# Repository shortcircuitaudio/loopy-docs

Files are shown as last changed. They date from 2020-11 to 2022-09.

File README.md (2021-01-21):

#  Loopy

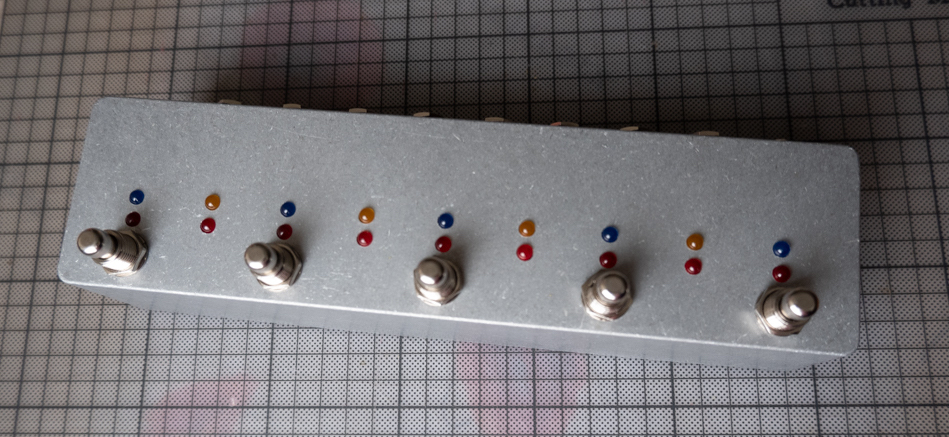
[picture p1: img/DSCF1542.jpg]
Looper


Loopy (LP8+) is a DIY 8 loop programmable guitar pedal switcher with support for MIDI commands.

Loopy is designed around easy-to-find components:
 - 1 atmega328(p) micro controller
 - 2 74HC595
 - 8 relays
 - several LED
 - several audio jack

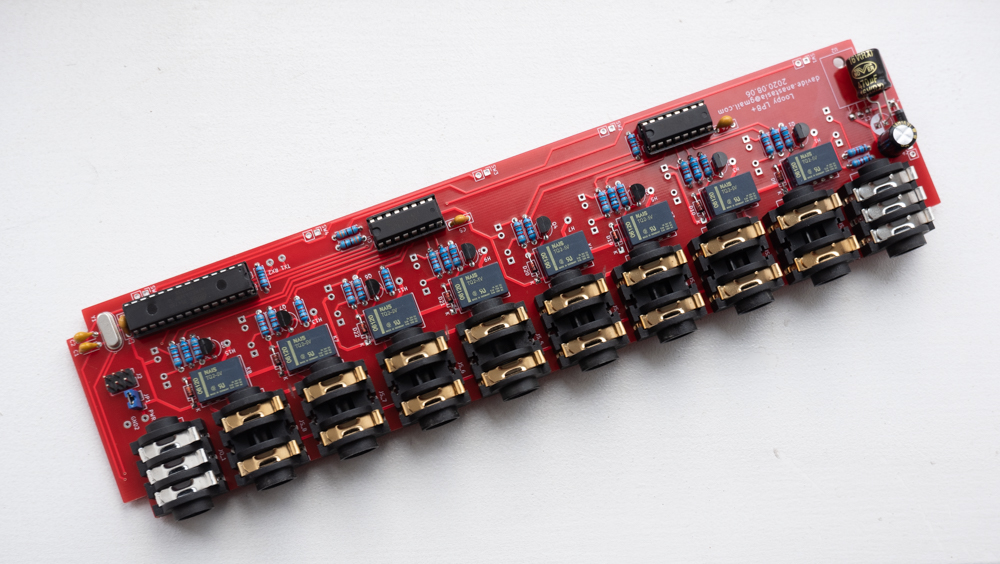
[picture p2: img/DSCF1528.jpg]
Main Board


This page is a collection of documents that can help you build your own looper.

##  FAQ

###  How does it work?

Have a look at the [Manual](./manual.md) for more info. There is a short video there too. I will try to film more to show all the available features.

###  Can you guide me through the build?

Please refer to the [How To Build Loopy](./howto.md) page.

###  Where can I find a PCB?

Please contact me if you need a PCB: I will try to have some available as long as there is demand for it. Alternatively, you can check [my eBay profile](https://www.ebay.co.uk/usr/daviderocker82it).

###  Why no display?

Rectangular holes (of good quality) are generally quite hard to make unless you have specialised tools, so I have put more effort on dislaying the status using LED, which only require round holes.

###  Does the signal go through a buffer?

No. Loopy doesn't contain any signal buffer: this gives the final user the flexibility to choose whether to have or not a buffer.

###  Is this an Arduino project?

No. While the micro controller used in this project is the same of the Arduino UNO, nothing of the Arduino platform is used: no bootloader, no USB port, no libraries. In fact, all the code is written from scratch in C++.

###  Can I build this project and sell it?

No. However, I could be interested in discussing a partnership. Please get in touch.

###  Can I have the source code of the firmware?

No. At the moment, I have decided to keep the source code private. However, HEX file for the firmware is available in this repo, and you are free to program your own chip with it.
Check the [instructions on how to setup your microcontroller](./firmware.md).

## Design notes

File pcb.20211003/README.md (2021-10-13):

# Loopy LP422

Notes

- Use drilling template from [pcb.20201125](../pcb.20201125/)
- Use connections from [pcb.20210226](../pcb.20210226/)

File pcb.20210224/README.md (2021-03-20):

## Notes

Use drilling template from [pcb.20201125](../pcb.20201125/)

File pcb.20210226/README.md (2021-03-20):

First experimental version of loopy, with 4+2+2 loops (4 pre, send/return, 2 post, 2 amp channel switcher)

## Notes

Use drilling template from [pcb.20201125](../pcb.20201125/)

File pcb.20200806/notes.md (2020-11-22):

# Notes

This is the first version of the PCB: only 5 have been made and they have long gone, so you can skip these documents unless you have one of these PCBs.

## Errata 

- As clear from the schematic, there is an error in the routing of the relays, so cuts were necessary on this version of the PCB to make it fully functional (I have uploaded the unmodified schematic to show where the problem is).
- wrong footprint for 7805 (package is TO220, but pinout is TO92): to solve, mount on the bottom side of the PCB
- (not mandatory) connect 5V+ to PIN 20 of U1

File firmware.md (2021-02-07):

# How to Program Loopy

In order to program Loopy, you need:
- an atmega328(p) chip
- an AVR programmer (an inexhpensive USBasp is perfectly fine, like the one [here](https://www.bitsbox.co.uk/index.php?main_page=product_info&cPath=140_161_163&products_id=1233))
- a 10 to 6 pin adapter if your programmer is not supplied with one, like the one [here](https://www.bitsbox.co.uk/index.php?main_page=product_info&cPath=140_161_163&products_id=2848)
- [avrdude](https://www.nongnu.org/avrdude/) correctly installed on your computer (installation are dependent on your OS of choice -- if you are on Mac, the easier way is to use [brew](https://formulae.brew.sh/formula/avrdude))

Once your computer is setup, you need to run three commands on your terminal.

The first command is mandatory to initialise the chip, and needs to be performed only on a blank chip. 

Once the initialisation is completed, the chip will work only if correctly connected to an oscillator: I strongly suggest to use the 6 pin header on the PCB to install the firmware.

## Fuses

If your chip has already a working copy of the firmware, you can skip this step. Otherwise, run:

```
avrdude -c usbasp -p atmega328p -B16 -U lfuse:w:0xFF:m -U hfuse:w:0xD9:m -U efuse:w:0xFF:m -U lock:w:0xFF:m
```

## Firwmare

The second command will upload the firmware on the chip:

```
avrdude -c usbasp -p atmega328p -U flash:w:<hex file location>
```

## EEPROM

The third command will setup the EEPROM, the portion of memory where the chip stores presets and config. The upload of the firmware will reset this location of memory, while running the following command will restore default values:

```
avrdude -c usbasp -p atmega328p -U eeprom:w:loopy.eep
```

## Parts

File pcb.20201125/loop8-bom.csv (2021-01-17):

Reference | Quantity | Value | Footprint | Datasheet
C1 C2 | 2 | 22p | Capacitor_THT:C_Disc_D4.3mm_W1.9mm_P5.00mm | ~
C3 | 1 | 470uF | Capacitor_THT:CP_Radial_D10.0mm_P5.00mm | ~
C4 | 1 | 1uF | Capacitor_THT:CP_Radial_D6.3mm_P2.50mm | ~
C5 C6 C7 C9 C11 | 5 | 100n | Capacitor_THT:C_Rect_L7.2mm_W2.5mm_P5.00mm_FKS2_FKP2_MKS2_MKP2 | ~
C8 C10 | 2 | 220uF | Capacitor_THT:CP_Radial_D8.0mm_P2.50mm | ~
D1 D2 D3 D4 D5 D6 D7 D8 D_S1 D11 D12 D13 D14 D15 D16 D17 D_S2 D18 | 18 | LED | dafx-kicad-lib:LED_D5.0mm | ~
D26 D27 | 2 | 1N4001 | Diode_THT:D_DO-41_SOD81_P10.16mm_Horizontal | http://www.vishay.com/docs/88503/1n4001.pdf
D9 D10 D19 D20 D21 D22 D23 D24 D25 | 9 | 1N914 | Diode_THT:D_DO-35_SOD27_P7.62mm_Horizontal | http://www.vishay.com/docs/85622/1n914.pdf
FB1 | 1 | Ferrite_Bead | 4MS:Ferrite_Bead_TH | ~
ISP1 | 1 | AVR-ISP-6 | Connector_PinHeader_2.54mm:PinHeader_2x03_P2.54mm_Vertical | ~
JI_1 JO_1 | 2 | NYS2152/NYS215 | Connector_Audio:Jack_3.5mm_Neutrik_NMJ6HCD2_Horizontal | ~
JP1 | 1 | Jumper_NO_Small | Connector_PinHeader_2.54mm:PinHeader_1x02_P2.54mm_Vertical | ~
JP2 | 1 | GND/GNDA | Connector_PinHeader_2.54mm:PinHeader_1x02_P2.54mm_Vertical | ~
JS_1 JR_2 JS_2 JR_3 JS_3 JR_4 JS_4 JR_5 JS_5 JS_6 JR_7 JS_7 JR_8 JS_8 JR_1 JR_6 | 16 | NYS2152/NYS215 | Connector_Audio:Jack_6.35mm_Neutrik_NMJ6HCD2_Horizontal | ~
K1 K2 K3 K4 K5 K6 K7 K8 | 8 | FRT5 | Relay_THT:Relay_DPDT_FRT5 | https://www.elpro.org/de/index.php?controller=attachment&id_attachment=8663
MIDI_OUT1 MIDI_IN1 | 2 | DIN-5 | dafx-kicad-lib:MIDI-HEADER | https://www.bitsbox.co.uk/index.php?main_page=product_info&cPath=225_226_300&products_id=1601
PWR_IN1 | 1 | Barrel_Jack | Connector_Wire:SolderWire-0.5sqmm_1x02_P4.6mm_D0.9mm_OD2.1mm | ~
Q1 Q2 Q3 Q4 Q5 Q6 Q7 Q8 | 8 | 2N3904 | Package_TO_SOT_THT:TO-92_Inline_Wide | https://www.fairchildsemi.com/datasheets/2N/2N3904.pdf
R1 R2 R3 R4 R5 R6 R7 R8 R19 R21 R22 R23 R24 R25 R26 R27 R18 R28 | 18 | 820R | Resistor_THT:R_Axial_DIN0207_L6.3mm_D2.5mm_P7.62mm_Horizontal | ~
R10 R11 R13 | 3 | 220R | Resistor_THT:R_Axial_DIN0207_L6.3mm_D2.5mm_P7.62mm_Horizontal | ~
R12 | 1 | 4k7 | Resistor_THT:R_Axial_DIN0207_L6.3mm_D2.5mm_P7.62mm_Horizontal | ~
R15 R20 R29 R30 R31 R32 R33 R34 | 8 | 1k | Resistor_THT:R_Axial_DIN0207_L6.3mm_D2.5mm_P7.62mm_Horizontal | ~
R17 R16 | 2 | 330R | Resistor_THT:R_Axial_DIN0207_L6.3mm_D2.5mm_P7.62mm_Horizontal | ~
R9 | 1 | 10k | Resistor_THT:R_Axial_DIN0207_L6.3mm_D2.5mm_P7.62mm_Horizontal | ~
SW1 SW2 SW3 SW4 SW5 | 5 | Momentary OFF/ON Footswitch | dafx-kicad-lib:PinHeader_1x02_P2.54mm_Vertical | ~
U1 | 1 | ATmega328P-PU | Package_DIP:DIP-28_W7.62mm | http://ww1.microchip.com/downloads/en/DeviceDoc/ATmega328_P%20AVR%20MCU%20with%20picoPower%20Technology%20Data%20Sheet%2040001984A.pdf
U2 | 1 | LM7805_TO220 | Package_TO_SOT_THT:TO-220-3_Horizontal_TabDown | http://www.fairchildsemi.com/ds/LM/LM7805.pdf
U3 U4 | 2 | 74HC595 | Package_DIP:DIP-16_W7.62mm | http://www.ti.com/lit/ds/symlink/sn74hc595.pdf
U5 | 1 | 6N138 | Package_DIP:DIP-8_W7.62mm | http://www.onsemi.com/pub/Collateral/HCPL2731-D.pdf
Y1 | 1 | 16Mhz | Crystal:Crystal_HC49-4H_Vertical | ~

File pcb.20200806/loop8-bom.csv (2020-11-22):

Reference | Value | Description & Notes | Datasheet | Footprint
C1 | 20p | Use multiplayer ceramic | ~ | Capacitor_THT:C_Disc_D4.3mm_W1.9mm_P5.00mm
C2 | 20p | use multiplayer ceramic | ~ | Capacitor_THT:C_Disc_D4.3mm_W1.9mm_P5.00mm
C3 | 470uF/16V | Footprint might be a bit small, I suggest to mount it liying on his side (check my photos on Facebook) | ~ | Capacitor_THT:CP_Radial_D6.3mm_P2.50mm
C4 | 220uF/16V |  | ~ | Capacitor_THT:CP_Radial_D6.3mm_P2.50mm
C5 | 100n | use multiplayer ceramic | ~ | Capacitor_THT:C_Rect_L7.2mm_W2.5mm_P5.00mm_FKS2_FKP2_MKS2_MKP2
C6 | 100n | use multiplayer ceramic | ~ | Capacitor_THT:C_Rect_L7.2mm_W2.5mm_P5.00mm_FKS2_FKP2_MKS2_MKP2
C7 | 100n | use multiplayer ceramic | ~ | Capacitor_THT:C_Rect_L7.2mm_W2.5mm_P5.00mm_FKS2_FKP2_MKS2_MKP2
D_S1 | LED |  | ~ | dafx-kicad-lib:LED_D5.0mm
D_S2 | LED |  | ~ | dafx-kicad-lib:LED_D5.0mm
D1 | LED |  | ~ | dafx-kicad-lib:LED_D5.0mm
D10 | 1N914 |  | http://www.vishay.com/docs/85622/1n914.pdf | Diode_THT:D_DO-35_SOD27_P7.62mm_Horizontal
D11 | LED |  | ~ | dafx-kicad-lib:LED_D5.0mm
D12 | LED |  | ~ | dafx-kicad-lib:LED_D5.0mm
D13 | LED |  | ~ | dafx-kicad-lib:LED_D5.0mm
D14 | LED |  | ~ | dafx-kicad-lib:LED_D5.0mm
D15 | LED |  | ~ | dafx-kicad-lib:LED_D5.0mm
D16 | LED |  | ~ | dafx-kicad-lib:LED_D5.0mm
D17 | LED |  | ~ | dafx-kicad-lib:LED_D5.0mm
D18 | LED |  | ~ | dafx-kicad-lib:LED_D5.0mm
D19 | 1N914 |  | http://www.vishay.com/docs/85622/1n914.pdf | Diode_THT:D_DO-35_SOD27_P7.62mm_Horizontal
D2 | LED |  | ~ | dafx-kicad-lib:LED_D5.0mm
D20 | 1N914 |  | http://www.vishay.com/docs/85622/1n914.pdf | Diode_THT:D_DO-35_SOD27_P7.62mm_Horizontal
D21 | 1N914 |  | http://www.vishay.com/docs/85622/1n914.pdf | Diode_THT:D_DO-35_SOD27_P7.62mm_Horizontal
D22 | 1N914 |  | http://www.vishay.com/docs/85622/1n914.pdf | Diode_THT:D_DO-35_SOD27_P7.62mm_Horizontal
D23 | 1N914 |  | http://www.vishay.com/docs/85622/1n914.pdf | Diode_THT:D_DO-35_SOD27_P7.62mm_Horizontal
D24 | 1N914 |  | http://www.vishay.com/docs/85622/1n914.pdf | Diode_THT:D_DO-35_SOD27_P7.62mm_Horizontal
D25 | 1N914 |  | http://www.vishay.com/docs/85622/1n914.pdf | Diode_THT:D_DO-35_SOD27_P7.62mm_Horizontal
D26 | 1N4001 |  | http://www.vishay.com/docs/88503/1n4001.pdf | Diode_THT:D_DO-41_SOD81_P10.16mm_Horizontal
D3 | LED |  | ~ | dafx-kicad-lib:LED_D5.0mm
D4 | LED |  | ~ | dafx-kicad-lib:LED_D5.0mm
D5 | LED |  | ~ | dafx-kicad-lib:LED_D5.0mm
D6 | LED |  | ~ | dafx-kicad-lib:LED_D5.0mm
D7 | LED |  | ~ | dafx-kicad-lib:LED_D5.0mm
D8 | LED |  | ~ | dafx-kicad-lib:LED_D5.0mm
D9 | 1N914 |  | http://www.vishay.com/docs/85622/1n914.pdf | Diode_THT:D_DO-35_SOD27_P7.62mm_Horizontal
GND1 | MountingHole_Pad |  | ~ | Connector_Wire:SolderWirePad_1x01_Drill0.8mm
GND2 | MountingHole_Pad |  | ~ | Connector_Wire:SolderWirePad_1x01_Drill0.8mm
H1 | MountingHole_Pad |  | ~ | Connector_Wire:SolderWirePad_1x01_Drill0.8mm
H10 | MountingHole_Pad |  | ~ | Connector_Wire:SolderWirePad_1x01_Drill0.8mm
H11 | MountingHole_Pad |  | ~ | Connector_Wire:SolderWirePad_1x01_Drill0.8mm
H12 | MountingHole_Pad |  | ~ | Connector_Wire:SolderWirePad_1x01_Drill0.8mm
H13 | MountingHole_Pad |  | ~ | Connector_Wire:SolderWirePad_1x01_Drill0.8mm
H14 | MountingHole_Pad |  | ~ | Connector_Wire:SolderWirePad_1x01_Drill0.8mm
H15 | MountingHole_Pad |  | ~ | Connector_Wire:SolderWirePad_1x01_Drill0.8mm
H16 | MountingHole_Pad |  | ~ | Connector_Wire:SolderWirePad_1x01_Drill0.8mm
H2 | MountingHole_Pad |  | ~ | Connector_Wire:SolderWirePad_1x01_Drill0.8mm
H3 | MountingHole_Pad |  | ~ | Connector_Wire:SolderWirePad_1x01_Drill0.8mm
H4 | MountingHole_Pad |  | ~ | Connector_Wire:SolderWirePad_1x01_Drill0.8mm
H5 | MountingHole_Pad |  | ~ | Connector_Wire:SolderWirePad_1x01_Drill0.8mm
H6 | MountingHole_Pad |  | ~ | Connector_Wire:SolderWirePad_1x01_Drill0.8mm
H7 | MountingHole_Pad |  | ~ | Connector_Wire:SolderWirePad_1x01_Drill0.8mm
H8 | MountingHole_Pad |  | ~ | Connector_Wire:SolderWirePad_1x01_Drill0.8mm
H9 | MountingHole_Pad |  | ~ | Connector_Wire:SolderWirePad_1x01_Drill0.8mm
J1 | Barrel_Jack | I usually use lumberg 2.1mm jacks for boss-style power | ~ | Connector_PinHeader_2.54mm:PinHeader_1x02_P2.54mm_Vertical
J2 | AVR-ISP-6 | you can cut this out a longer 2 line strip | ~ | Connector_PinHeader_2.54mm:PinHeader_2x03_P2.54mm_Vertical
J3 | DIN-5_180degree | MIDI, panel mount | http://www.mouser.com/ds/2/18/40_c091_abd_e-75918.pdf | Connector_PinHeader_2.54mm:PinHeader_1x05_P2.54mm_Vertical
J4 | DIN-5_180degree | MIDI, panel mount | http://www.mouser.com/ds/2/18/40_c091_abd_e-75918.pdf | Connector_PinHeader_2.54mm:PinHeader_1x05_P2.54mm_Vertical
JI_1 | AudioJack3_Switch |  | ~ | Connector_Audio:Jack_3.5mm_Neutrik_NMJ6HCD2_Horizontal
JO_1 | AudioJack3_Switch |  | ~ | Connector_Audio:Jack_3.5mm_Neutrik_NMJ6HCD2_Horizontal
JP1 | Jumper_NO_Small |  | ~ | Connector_PinHeader_2.54mm:PinHeader_1x02_P2.54mm_Vertical
JR_1 | AudioJack3_Switch |  | ~ | Connector_Audio:Jack_3.5mm_Neutrik_NMJ6HCD2_Horizontal
JR_2 | AudioJack3_Switch |  | ~ | Connector_Audio:Jack_3.5mm_Neutrik_NMJ6HCD2_Horizontal
JR_3 | AudioJack3_Switch |  | ~ | Connector_Audio:Jack_3.5mm_Neutrik_NMJ6HCD2_Horizontal
JR_4 | AudioJack3_Switch |  | ~ | Connector_Audio:Jack_3.5mm_Neutrik_NMJ6HCD2_Horizontal
JR_5 | AudioJack3_Switch |  | ~ | Connector_Audio:Jack_3.5mm_Neutrik_NMJ6HCD2_Horizontal
JR_6 | AudioJack3_Switch |  | ~ | Connector_Audio:Jack_3.5mm_Neutrik_NMJ6HCD2_Horizontal
JR_7 | AudioJack3_Switch |  | ~ | Connector_Audio:Jack_3.5mm_Neutrik_NMJ6HCD2_Horizontal
JR_8 | AudioJack3_Switch |  | ~ | Connector_Audio:Jack_3.5mm_Neutrik_NMJ6HCD2_Horizontal
JS_1 | AudioJack3_Switch |  | ~ | Connector_Audio:Jack_3.5mm_Neutrik_NMJ6HCD2_Horizontal
JS_2 | AudioJack3_Switch |  | ~ | Connector_Audio:Jack_3.5mm_Neutrik_NMJ6HCD2_Horizontal
JS_3 | AudioJack3_Switch |  | ~ | Connector_Audio:Jack_3.5mm_Neutrik_NMJ6HCD2_Horizontal
JS_4 | AudioJack3_Switch |  | ~ | Connector_Audio:Jack_3.5mm_Neutrik_NMJ6HCD2_Horizontal
JS_5 | AudioJack3_Switch |  | ~ | Connector_Audio:Jack_3.5mm_Neutrik_NMJ6HCD2_Horizontal
JS_6 | AudioJack3_Switch |  | ~ | Connector_Audio:Jack_3.5mm_Neutrik_NMJ6HCD2_Horizontal
JS_7 | AudioJack3_Switch |  | ~ | Connector_Audio:Jack_3.5mm_Neutrik_NMJ6HCD2_Horizontal
JS_8 | AudioJack3_Switch |  | ~ | Connector_Audio:Jack_3.5mm_Neutrik_NMJ6HCD2_Horizontal
K1 | FRT5 |  | https://www.elpro.org/de/index.php?controller=attachment&id_attachment=8663 | Relay_THT:Relay_DPDT_FRT5
K2 | FRT5 |  | https://www.elpro.org/de/index.php?controller=attachment&id_attachment=8663 | Relay_THT:Relay_DPDT_FRT5
K3 | FRT5 |  | https://www.elpro.org/de/index.php?controller=attachment&id_attachment=8663 | Relay_THT:Relay_DPDT_FRT5
K4 | FRT5 |  | https://www.elpro.org/de/index.php?controller=attachment&id_attachment=8663 | Relay_THT:Relay_DPDT_FRT5
K5 | FRT5 |  | https://www.elpro.org/de/index.php?controller=attachment&id_attachment=8663 | Relay_THT:Relay_DPDT_FRT5
K6 | FRT5 |  | https://www.elpro.org/de/index.php?controller=attachment&id_attachment=8663 | Relay_THT:Relay_DPDT_FRT5
K7 | FRT5 |  | https://www.elpro.org/de/index.php?controller=attachment&id_attachment=8663 | Relay_THT:Relay_DPDT_FRT5
K8 | FRT5 |  | https://www.elpro.org/de/index.php?controller=attachment&id_attachment=8663 | Relay_THT:Relay_DPDT_FRT5
PWR1 | MountingHole_Pad |  | ~ | Connector_Wire:SolderWirePad_1x01_Drill0.8mm
PWR2 | MountingHole_Pad |  | ~ | Connector_Wire:SolderWirePad_1x01_Drill0.8mm
Q1 | 2N3904 |  | https://www.fairchildsemi.com/datasheets/2N/2N3904.pdf | Package_TO_SOT_THT:TO-92_Inline_Wide
Q2 | 2N3904 |  | https://www.fairchildsemi.com/datasheets/2N/2N3904.pdf | Package_TO_SOT_THT:TO-92_Inline_Wide
Q3 | 2N3904 |  | https://www.fairchildsemi.com/datasheets/2N/2N3904.pdf | Package_TO_SOT_THT:TO-92_Inline_Wide
Q4 | 2N3904 |  | https://www.fairchildsemi.com/datasheets/2N/2N3904.pdf | Package_TO_SOT_THT:TO-92_Inline_Wide
Q5 | 2N3904 |  | https://www.fairchildsemi.com/datasheets/2N/2N3904.pdf | Package_TO_SOT_THT:TO-92_Inline_Wide
Q6 | 2N3904 |  | https://www.fairchildsemi.com/datasheets/2N/2N3904.pdf | Package_TO_SOT_THT:TO-92_Inline_Wide
Q7 | 2N3904 |  | https://www.fairchildsemi.com/datasheets/2N/2N3904.pdf | Package_TO_SOT_THT:TO-92_Inline_Wide
Q8 | 2N3904 |  | https://www.fairchildsemi.com/datasheets/2N/2N3904.pdf | Package_TO_SOT_THT:TO-92_Inline_Wide
R1 | 1k |  | ~ | Resistor_THT:R_Axial_DIN0207_L6.3mm_D2.5mm_P7.62mm_Horizontal
R10 | 220R |  | ~ | Resistor_THT:R_Axial_DIN0207_L6.3mm_D2.5mm_P7.62mm_Horizontal
R11 | 220R |  | ~ | Resistor_THT:R_Axial_DIN0207_L6.3mm_D2.5mm_P7.62mm_Horizontal
R12 | 4k7 |  | ~ | Resistor_THT:R_Axial_DIN0207_L6.3mm_D2.5mm_P7.62mm_Horizontal
R13 | 220R |  | ~ | Resistor_THT:R_Axial_DIN0207_L6.3mm_D2.5mm_P7.62mm_Horizontal
R14 | 512k |  | ~ | Resistor_THT:R_Axial_DIN0207_L6.3mm_D2.5mm_P7.62mm_Horizontal
R15 | 1k |  | ~ | Resistor_THT:R_Axial_DIN0207_L6.3mm_D2.5mm_P7.62mm_Horizontal
R16 | 330R |  | ~ | Resistor_THT:R_Axial_DIN0207_L6.3mm_D2.5mm_P7.62mm_Horizontal
R17 | 330R |  | ~ | Resistor_THT:R_Axial_DIN0207_L6.3mm_D2.5mm_P7.62mm_Horizontal
R18 | 1k |  | ~ | Resistor_THT:R_Axial_DIN0207_L6.3mm_D2.5mm_P7.62mm_Horizontal
R19 | 1k |  | ~ | Resistor_THT:R_Axial_DIN0207_L6.3mm_D2.5mm_P7.62mm_Horizontal
R2 | 1k |  | ~ | Resistor_THT:R_Axial_DIN0207_L6.3mm_D2.5mm_P7.62mm_Horizontal
R20 | 1k |  | ~ | Resistor_THT:R_Axial_DIN0207_L6.3mm_D2.5mm_P7.62mm_Horizontal
R21 | 1k |  | ~ | Resistor_THT:R_Axial_DIN0207_L6.3mm_D2.5mm_P7.62mm_Horizontal
R22 | 1k |  | ~ | Resistor_THT:R_Axial_DIN0207_L6.3mm_D2.5mm_P7.62mm_Horizontal
R23 | 1k |  | ~ | Resistor_THT:R_Axial_DIN0207_L6.3mm_D2.5mm_P7.62mm_Horizontal
R24 | 1k |  | ~ | Resistor_THT:R_Axial_DIN0207_L6.3mm_D2.5mm_P7.62mm_Horizontal
R25 | 1k |  | ~ | Resistor_THT:R_Axial_DIN0207_L6.3mm_D2.5mm_P7.62mm_Horizontal
R26 | 1k |  | ~ | Resistor_THT:R_Axial_DIN0207_L6.3mm_D2.5mm_P7.62mm_Horizontal
R27 | 1k |  | ~ | Resistor_THT:R_Axial_DIN0207_L6.3mm_D2.5mm_P7.62mm_Horizontal
R28 | 1k |  | ~ | Resistor_THT:R_Axial_DIN0207_L6.3mm_D2.5mm_P7.62mm_Horizontal
R29 | 1k |  | ~ | Resistor_THT:R_Axial_DIN0207_L6.3mm_D2.5mm_P7.62mm_Horizontal
R3 | 1k |  | ~ | Resistor_THT:R_Axial_DIN0207_L6.3mm_D2.5mm_P7.62mm_Horizontal
R30 | 1k |  | ~ | Resistor_THT:R_Axial_DIN0207_L6.3mm_D2.5mm_P7.62mm_Horizontal
R31 | 1k |  | ~ | Resistor_THT:R_Axial_DIN0207_L6.3mm_D2.5mm_P7.62mm_Horizontal
R32 | 1k |  | ~ | Resistor_THT:R_Axial_DIN0207_L6.3mm_D2.5mm_P7.62mm_Horizontal
R33 | 1k |  | ~ | Resistor_THT:R_Axial_DIN0207_L6.3mm_D2.5mm_P7.62mm_Horizontal
R34 | 1k |  | ~ | Resistor_THT:R_Axial_DIN0207_L6.3mm_D2.5mm_P7.62mm_Horizontal
R35 | 512k |  | ~ | Resistor_THT:R_Axial_DIN0207_L6.3mm_D2.5mm_P7.62mm_Horizontal
R36 | 512k |  | ~ | Resistor_THT:R_Axial_DIN0207_L6.3mm_D2.5mm_P7.62mm_Horizontal
R37 | 512k |  | ~ | Resistor_THT:R_Axial_DIN0207_L6.3mm_D2.5mm_P7.62mm_Horizontal
R38 | 512k |  | ~ | Resistor_THT:R_Axial_DIN0207_L6.3mm_D2.5mm_P7.62mm_Horizontal
R39 | 512k |  | ~ | Resistor_THT:R_Axial_DIN0207_L6.3mm_D2.5mm_P7.62mm_Horizontal
R4 | 1k |  | ~ | Resistor_THT:R_Axial_DIN0207_L6.3mm_D2.5mm_P7.62mm_Horizontal
R40 | 512k |  | ~ | Resistor_THT:R_Axial_DIN0207_L6.3mm_D2.5mm_P7.62mm_Horizontal
R41 | 512k |  | ~ | Resistor_THT:R_Axial_DIN0207_L6.3mm_D2.5mm_P7.62mm_Horizontal
R5 | 1k |  | ~ | Resistor_THT:R_Axial_DIN0207_L6.3mm_D2.5mm_P7.62mm_Horizontal
R6 | 1k |  | ~ | Resistor_THT:R_Axial_DIN0207_L6.3mm_D2.5mm_P7.62mm_Horizontal
R7 | 1k |  | ~ | Resistor_THT:R_Axial_DIN0207_L6.3mm_D2.5mm_P7.62mm_Horizontal
R8 | 1k |  | ~ | Resistor_THT:R_Axial_DIN0207_L6.3mm_D2.5mm_P7.62mm_Horizontal
R9 | R_US |  | ~ | Resistor_THT:R_Axial_DIN0207_L6.3mm_D2.5mm_P7.62mm_Horizontal
RX1 | MountingHole_Pad |  | ~ | Connector_Wire:SolderWirePad_1x01_Drill0.8mm
RX2 | MountingHole_Pad |  | ~ | Connector_Wire:SolderWirePad_1x01_Drill0.8mm
SW1 | SW_Push | Momentary Push Button (Carling Style) | ~ | Connector_PinHeader_2.54mm:PinHeader_1x02_P2.54mm_Vertical
SW2 | SW_Push | Momentary Push Button (Carling Style) | ~ | Connector_PinHeader_2.54mm:PinHeader_1x02_P2.54mm_Vertical
SW3 | SW_Push | Momentary Push Button (Carling Style) | ~ | Connector_PinHeader_2.54mm:PinHeader_1x02_P2.54mm_Vertical
SW4 | SW_Push | Momentary Push Button (Carling Style) | ~ | Connector_PinHeader_2.54mm:PinHeader_1x02_P2.54mm_Vertical
SW5 | SW_Push | Momentary Push Button (Carling Style) | ~ | Connector_PinHeader_2.54mm:PinHeader_1x02_P2.54mm_Vertical
TX1 | MountingHole_Pad |  | ~ | Connector_Wire:SolderWirePad_1x01_Drill0.8mm
TX2 | MountingHole_Pad |  | ~ | Connector_Wire:SolderWirePad_1x01_Drill0.8mm
U1 | ATmega328P-PU |  | http://ww1.microchip.com/downloads/en/DeviceDoc/ATmega328_P%20AVR%20MCU%20with%20picoPower%20Technology%20Data%20Sheet%2040001984A.pdf | Package_DIP:DIP-28_W7.62mm
U2 | L78L05_TO92 | Mount on the bottom of the board | http://www.st.com/content/ccc/resource/technical/document/datasheet/15/55/e5/aa/23/5b/43/fd/CD00000446.pdf/files/CD00000446.pdf/jcr:content/translations/en.CD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 | Package_TO_SOT_THT:TO-220-3_Horizontal_TabDown
U3 | 74HC595 |  | http://www.ti.com/lit/ds/symlink/sn74hc595.pdf | Package_DIP:DIP-16_W7.62mm
U4 | 74HC595 |  | http://www.ti.com/lit/ds/symlink/sn74hc595.pdf | Package_DIP:DIP-16_W7.62mm
U5 | 6N138 |  | http://www.onsemi.com/pub/Collateral/HCPL2731-D.pdf | Package_DIP:DIP-8_W7.62mm
Y1 | Crystal | Only 16Mhz will work in the design | 16Mhz Low Profile | Crystal:Crystal_HC49-4H_Vertical

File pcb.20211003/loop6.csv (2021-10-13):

Reference | Value | Footprint | Datasheet
C1 | 22p | Capacitor_THT:C_Disc_D4.3mm_W1.9mm_P5.00mm | ~
C10 | 220uF | Capacitor_THT:CP_Radial_D8.0mm_P2.50mm | ~
C11 | 100n | Capacitor_THT:C_Rect_L7.2mm_W2.5mm_P5.00mm_FKS2_FKP2_MKS2_MKP2 | ~
C2 | 22p | Capacitor_THT:C_Disc_D4.3mm_W1.9mm_P5.00mm | ~
C3 | 470uF/25V | Capacitor_THT:CP_Radial_D10.0mm_P5.00mm | ~
C4 | 1uF | Capacitor_THT:CP_Radial_D6.3mm_P2.50mm | ~
C5 | 100n | Capacitor_THT:C_Rect_L7.2mm_W2.5mm_P5.00mm_FKS2_FKP2_MKS2_MKP2 | ~
C6 | 100n | Capacitor_THT:C_Rect_L7.2mm_W2.5mm_P5.00mm_FKS2_FKP2_MKS2_MKP2 | ~
C7 | 100n | Capacitor_THT:C_Rect_L7.2mm_W2.5mm_P5.00mm_FKS2_FKP2_MKS2_MKP2 | ~
C8 | 220uF/16V | Capacitor_THT:CP_Radial_D8.0mm_P2.50mm | ~
C9 | 100n | Capacitor_THT:C_Rect_L7.2mm_W2.5mm_P5.00mm_FKS2_FKP2_MKS2_MKP2 | ~
D_S1 | LED | dafx-kicad-lib:LED_D5.0mm | ~
D_S2 | LED | dafx-kicad-lib:LED_D5.0mm | ~
D1 | LED | dafx-kicad-lib:LED_D5.0mm | ~
D10 | 1N914 | Diode_THT:D_DO-35_SOD27_P7.62mm_Horizontal | http://www.vishay.com/docs/85622/1n914.pdf
D11 | LED | dafx-kicad-lib:LED_D5.0mm | ~
D12 | LED | dafx-kicad-lib:LED_D5.0mm | ~
D13 | LED | dafx-kicad-lib:LED_D5.0mm | ~
D14 | LED | dafx-kicad-lib:LED_D5.0mm | ~
D15 | LED | dafx-kicad-lib:LED_D5.0mm | ~
D16 | LED | dafx-kicad-lib:LED_D5.0mm | ~
D17 | LED | dafx-kicad-lib:LED_D5.0mm | ~
D18 | LED | dafx-kicad-lib:LED_D5.0mm | ~
D19 | 1N914 | Diode_THT:D_DO-35_SOD27_P7.62mm_Horizontal | http://www.vishay.com/docs/85622/1n914.pdf
D2 | LED | dafx-kicad-lib:LED_D5.0mm | ~
D20 | 1N914 | Diode_THT:D_DO-35_SOD27_P7.62mm_Horizontal | http://www.vishay.com/docs/85622/1n914.pdf
D21 | 1N914 | Diode_THT:D_DO-35_SOD27_P7.62mm_Horizontal | http://www.vishay.com/docs/85622/1n914.pdf
D22 | 1N914 | Diode_THT:D_DO-35_SOD27_P7.62mm_Horizontal | http://www.vishay.com/docs/85622/1n914.pdf
D23 | 1N914 | Diode_THT:D_DO-35_SOD27_P7.62mm_Horizontal | http://www.vishay.com/docs/85622/1n914.pdf
D24 | 1N914 | Diode_THT:D_DO-35_SOD27_P7.62mm_Horizontal | http://www.vishay.com/docs/85622/1n914.pdf
D25 | 1N914 | Diode_THT:D_DO-35_SOD27_P7.62mm_Horizontal | http://www.vishay.com/docs/85622/1n914.pdf
D26 | 1N4001 | Diode_THT:D_DO-41_SOD81_P10.16mm_Horizontal | http://www.vishay.com/docs/88503/1n4001.pdf
D27 | 1N4001 | Diode_THT:D_DO-41_SOD81_P10.16mm_Horizontal | http://www.vishay.com/docs/88503/1n4001.pdf
D3 | LED | dafx-kicad-lib:LED_D5.0mm | ~
D4 | LED | dafx-kicad-lib:LED_D5.0mm | ~
D5 | LED | dafx-kicad-lib:LED_D5.0mm | ~
D6 | LED | dafx-kicad-lib:LED_D5.0mm | ~
D7 | LED | dafx-kicad-lib:LED_D5.0mm | ~
D8 | LED | dafx-kicad-lib:LED_D5.0mm | ~
D9 | 1N914 | Diode_THT:D_DO-35_SOD27_P7.62mm_Horizontal | http://www.vishay.com/docs/85622/1n914.pdf
FB1 | Ferrite_Bead | 4MS:Ferrite_Bead_TH | ~
ISP1 | AVR-ISP-6 | Connector_PinHeader_2.54mm:PinHeader_2x03_P2.54mm_Vertical | ~
JI_1 | NYS2152/NYS215 | Connector_Audio:Jack_6.35mm_Neutrik_NMJ6HCD2_Horizontal | ~
JO_1 | NYS2152/NYS215 | Connector_Audio:Jack_6.35mm_Neutrik_NMJ6HCD2_Horizontal | ~
JP1 | Jumper_NO_Small | Connector_PinHeader_2.54mm:PinHeader_1x02_P2.54mm_Vertical | ~
JP2 | GND/GNDA | Connector_PinHeader_2.54mm:PinHeader_1x02_P2.54mm_Vertical | ~
JR_1 | NYS2152/NYS215 | Connector_Audio:Jack_6.35mm_Neutrik_NMJ6HCD2_Horizontal | ~
JR_2 | NYS2152/NYS215 | Connector_Audio:Jack_6.35mm_Neutrik_NMJ6HCD2_Horizontal | ~
JR_3 | NYS2152/NYS215 | Connector_Audio:Jack_6.35mm_Neutrik_NMJ6HCD2_Horizontal | ~
JR_4 | NYS2152/NYS215 | Connector_Audio:Jack_6.35mm_Neutrik_NMJ6HCD2_Horizontal | ~
JR_5 | NYS2152/NYS215 | Connector_Audio:Jack_6.35mm_Neutrik_NMJ6HCD2_Horizontal | ~
JR_6 | NYS2152/NYS215 | Connector_Audio:Jack_6.35mm_Neutrik_NMJ6HCD2_Horizontal | ~
JR_7 | NYS2152/NYS215 | Connector_Audio:Jack_6.35mm_Neutrik_NMJ6HCD2_Horizontal | ~
JR_8 | NYS2152/NYS215 | Connector_Audio:Jack_6.35mm_Neutrik_NMJ6HCD2_Horizontal | ~
JS_1 | NYS2152/NYS215 | Connector_Audio:Jack_6.35mm_Neutrik_NMJ6HCD2_Horizontal | ~
JS_2 | NYS2152/NYS215 | Connector_Audio:Jack_6.35mm_Neutrik_NMJ6HCD2_Horizontal | ~
JS_3 | NYS2152/NYS215 | Connector_Audio:Jack_6.35mm_Neutrik_NMJ6HCD2_Horizontal | ~
JS_4 | NYS2152/NYS215 | Connector_Audio:Jack_6.35mm_Neutrik_NMJ6HCD2_Horizontal | ~
JS_5 | NYS2152/NYS215 | Connector_Audio:Jack_6.35mm_Neutrik_NMJ6HCD2_Horizontal | ~
JS_6 | NYS2152/NYS215 | Connector_Audio:Jack_6.35mm_Neutrik_NMJ6HCD2_Horizontal | ~
JS_7 | NYS2152/NYS215 | Connector_Audio:Jack_6.35mm_Neutrik_NMJ6HCD2_Horizontal | ~
JS_8 | NYS2152/NYS215 | Connector_Audio:Jack_6.35mm_Neutrik_NMJ6HCD2_Horizontal | ~
K1 | FRT5 | Relay_THT:Relay_DPDT_FRT5 | https://www.elpro.org/de/index.php?controller=attachment&id_attachment=8663
K2 | FRT5 | Relay_THT:Relay_DPDT_FRT5 | https://www.elpro.org/de/index.php?controller=attachment&id_attachment=8663
K3 | FRT5 | Relay_THT:Relay_DPDT_FRT5 | https://www.elpro.org/de/index.php?controller=attachment&id_attachment=8663
K4 | FRT5 | Relay_THT:Relay_DPDT_FRT5 | https://www.elpro.org/de/index.php?controller=attachment&id_attachment=8663
K5 | FRT5 | Relay_THT:Relay_DPDT_FRT5 | https://www.elpro.org/de/index.php?controller=attachment&id_attachment=8663
K6 | FRT5 | Relay_THT:Relay_DPDT_FRT5 | https://www.elpro.org/de/index.php?controller=attachment&id_attachment=8663
K7 | G5V-1 | Relay_THT:Relay_SPDT_Omron_G5V-1 | http://omronfs.omron.com/en_US/ecb/products/pdf/en-g5v_1.pdf
K8 | G5V-1 | Relay_THT:Relay_SPDT_Omron_G5V-1 | http://omronfs.omron.com/en_US/ecb/products/pdf/en-g5v_1.pdf
MIDI_IN1 | DIN-5 | dafx-kicad-lib:MIDI-HEADER | https://www.bitsbox.co.uk/index.php?main_page=product_info&cPath=225_226_300&products_id=1601
MIDI_OUT1 | DIN-5 | dafx-kicad-lib:MIDI-HEADER | https://www.bitsbox.co.uk/index.php?main_page=product_info&cPath=225_226_300&products_id=1601
Q1 | 2N3904 | Package_TO_SOT_THT:TO-92_Inline_Wide | https://www.fairchildsemi.com/datasheets/2N/2N3904.pdf
Q2 | 2N3904 | Package_TO_SOT_THT:TO-92_Inline_Wide | https://www.fairchildsemi.com/datasheets/2N/2N3904.pdf
Q3 | 2N3904 | Package_TO_SOT_THT:TO-92_Inline_Wide | https://www.fairchildsemi.com/datasheets/2N/2N3904.pdf
Q4 | 2N3904 | Package_TO_SOT_THT:TO-92_Inline_Wide | https://www.fairchildsemi.com/datasheets/2N/2N3904.pdf
Q5 | 2N3904 | Package_TO_SOT_THT:TO-92_Inline_Wide | https://www.fairchildsemi.com/datasheets/2N/2N3904.pdf
Q6 | 2N3904 | Package_TO_SOT_THT:TO-92_Inline_Wide | https://www.fairchildsemi.com/datasheets/2N/2N3904.pdf
Q7 | 2N3904 | Package_TO_SOT_THT:TO-92_Inline_Wide | https://www.fairchildsemi.com/datasheets/2N/2N3904.pdf
Q8 | 2N3904 | Package_TO_SOT_THT:TO-92_Inline_Wide | https://www.fairchildsemi.com/datasheets/2N/2N3904.pdf
R1 | 820R | Resistor_THT:R_Axial_DIN0207_L6.3mm_D2.5mm_P7.62mm_Horizontal | ~
R10 | 220R | Resistor_THT:R_Axial_DIN0207_L6.3mm_D2.5mm_P7.62mm_Horizontal | ~
R11 | 220R | Resistor_THT:R_Axial_DIN0207_L6.3mm_D2.5mm_P7.62mm_Horizontal | ~
R12 | 4k7 | Resistor_THT:R_Axial_DIN0207_L6.3mm_D2.5mm_P7.62mm_Horizontal | ~
R13 | 220R | Resistor_THT:R_Axial_DIN0207_L6.3mm_D2.5mm_P7.62mm_Horizontal | ~
R14 | 100R | Resistor_THT:R_Axial_DIN0207_L6.3mm_D2.5mm_P7.62mm_Horizontal | ~
R15 | 1k | Resistor_THT:R_Axial_DIN0207_L6.3mm_D2.5mm_P7.62mm_Horizontal | ~
R16 | 330R | Resistor_THT:R_Axial_DIN0207_L6.3mm_D2.5mm_P7.62mm_Horizontal | ~
R17 | 330R | Resistor_THT:R_Axial_DIN0207_L6.3mm_D2.5mm_P7.62mm_Horizontal | ~
R18 | 820R | Resistor_THT:R_Axial_DIN0207_L6.3mm_D2.5mm_P7.62mm_Horizontal | ~
R19 | 820R | Resistor_THT:R_Axial_DIN0207_L6.3mm_D2.5mm_P7.62mm_Horizontal | ~
R2 | 820R | Resistor_THT:R_Axial_DIN0207_L6.3mm_D2.5mm_P7.62mm_Horizontal | ~
R20 | 1k | Resistor_THT:R_Axial_DIN0207_L6.3mm_D2.5mm_P7.62mm_Horizontal | ~
R21 | 820R | Resistor_THT:R_Axial_DIN0207_L6.3mm_D2.5mm_P7.62mm_Horizontal | ~
R22 | 820R | Resistor_THT:R_Axial_DIN0207_L6.3mm_D2.5mm_P7.62mm_Horizontal | ~
R23 | 820R | Resistor_THT:R_Axial_DIN0207_L6.3mm_D2.5mm_P7.62mm_Horizontal | ~
R24 | 820R | Resistor_THT:R_Axial_DIN0207_L6.3mm_D2.5mm_P7.62mm_Horizontal | ~
R25 | 820R | Resistor_THT:R_Axial_DIN0207_L6.3mm_D2.5mm_P7.62mm_Horizontal | ~
R26 | 820R | Resistor_THT:R_Axial_DIN0207_L6.3mm_D2.5mm_P7.62mm_Horizontal | ~
R27 | 820R | Resistor_THT:R_Axial_DIN0207_L6.3mm_D2.5mm_P7.62mm_Horizontal | ~
R28 | 820R | Resistor_THT:R_Axial_DIN0207_L6.3mm_D2.5mm_P7.62mm_Horizontal | ~
R29 | 1k | Resistor_THT:R_Axial_DIN0207_L6.3mm_D2.5mm_P7.62mm_Horizontal | ~
R3 | 820R | Resistor_THT:R_Axial_DIN0207_L6.3mm_D2.5mm_P7.62mm_Horizontal | ~
R30 | 1k | Resistor_THT:R_Axial_DIN0207_L6.3mm_D2.5mm_P7.62mm_Horizontal | ~
R31 | 1k | Resistor_THT:R_Axial_DIN0207_L6.3mm_D2.5mm_P7.62mm_Horizontal | ~
R32 | 1k | Resistor_THT:R_Axial_DIN0207_L6.3mm_D2.5mm_P7.62mm_Horizontal | ~
R33 | 1k | Resistor_THT:R_Axial_DIN0207_L6.3mm_D2.5mm_P7.62mm_Horizontal | ~
R34 | 1k | Resistor_THT:R_Axial_DIN0207_L6.3mm_D2.5mm_P7.62mm_Horizontal | ~
R4 | 820R | Resistor_THT:R_Axial_DIN0207_L6.3mm_D2.5mm_P7.62mm_Horizontal | ~
R5 | 820R | Resistor_THT:R_Axial_DIN0207_L6.3mm_D2.5mm_P7.62mm_Horizontal | ~
R6 | 820R | Resistor_THT:R_Axial_DIN0207_L6.3mm_D2.5mm_P7.62mm_Horizontal | ~
R7 | 820R | Resistor_THT:R_Axial_DIN0207_L6.3mm_D2.5mm_P7.62mm_Horizontal | ~
R8 | 820R | Resistor_THT:R_Axial_DIN0207_L6.3mm_D2.5mm_P7.62mm_Horizontal | ~
R9 | 10k | Resistor_THT:R_Axial_DIN0207_L6.3mm_D2.5mm_P7.62mm_Horizontal | ~
SW1 | Momentary Push Button | dafx-kicad-lib:PinHeader_1x02_P2.54mm_Vertical | ~
SW2 | Momentary Push Button | dafx-kicad-lib:PinHeader_1x02_P2.54mm_Vertical | ~
SW3 | Momentary Push Button | dafx-kicad-lib:PinHeader_1x02_P2.54mm_Vertical | ~
SW4 | Momentary Push Button | dafx-kicad-lib:PinHeader_1x02_P2.54mm_Vertical | ~
SW5 | Momentary Push Button | dafx-kicad-lib:PinHeader_1x02_P2.54mm_Vertical | ~
U1 | ATmega328P-PU | Package_DIP:DIP-28_W7.62mm | http://ww1.microchip.com/downloads/en/DeviceDoc/ATmega328_P%20AVR%20MCU%20with%20picoPower%20Technology%20Data%20Sheet%2040001984A.pdf
U2 | LM7805_TO220 | Package_TO_SOT_THT:TO-220-3_Horizontal_TabDown | http://www.fairchildsemi.com/ds/LM/LM7805.pdf
U3 | 74HC595 | Package_DIP:DIP-16_W7.62mm | http://www.ti.com/lit/ds/symlink/sn74hc595.pdf
U4 | 74HC595 | Package_DIP:DIP-16_W7.62mm | http://www.ti.com/lit/ds/symlink/sn74hc595.pdf
U5 | 6N138 | Package_DIP:DIP-8_W7.62mm | http://www.onsemi.com/pub/Collateral/HCPL2731-D.pdf
Y1 | 16Mhz | Crystal:Crystal_HC49-4H_Vertical | ~

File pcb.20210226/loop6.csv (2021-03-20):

Reference | Value | Footprint | Datasheet
Y1 | 16Mhz | Crystal:Crystal_HC49-4H_Vertical | ~
C1 | 22p | Capacitor_THT:C_Disc_D4.3mm_W1.9mm_P5.00mm | ~
C2 | 22p | Capacitor_THT:C_Disc_D4.3mm_W1.9mm_P5.00mm | ~
U1 | ATmega328P-PU | Package_DIP:DIP-28_W7.62mm | http://ww1.microchip.com/downloads/en/DeviceDoc/ATmega328_P%20AVR%20MCU%20with%20picoPower%20Technology%20Data%20Sheet%2040001984A.pdf
ISP1 | AVR-ISP-6 | Connector_PinHeader_2.54mm:PinHeader_2x03_P2.54mm_Vertical | ~
C3 | 470uF | Capacitor_THT:CP_Radial_D10.0mm_P5.00mm | ~
C4 | 1uF | Capacitor_THT:CP_Radial_D6.3mm_P2.50mm | ~
U3 | 74HC595 | Package_DIP:DIP-16_W7.62mm | http://www.ti.com/lit/ds/symlink/sn74hc595.pdf
D1 | LED | dafx-kicad-lib:LED_D5.0mm | ~
D2 | LED | dafx-kicad-lib:LED_D5.0mm | ~
D3 | LED | dafx-kicad-lib:LED_D5.0mm | ~
D4 | LED | dafx-kicad-lib:LED_D5.0mm | ~
D5 | LED | dafx-kicad-lib:LED_D5.0mm | ~
D6 | LED | dafx-kicad-lib:LED_D5.0mm | ~
D7 | LED | dafx-kicad-lib:LED_D5.0mm | ~
D8 | LED | dafx-kicad-lib:LED_D5.0mm | ~
R1 | 820R | Resistor_THT:R_Axial_DIN0207_L6.3mm_D2.5mm_P7.62mm_Horizontal | ~
R2 | 820R | Resistor_THT:R_Axial_DIN0207_L6.3mm_D2.5mm_P7.62mm_Horizontal | ~
R3 | 820R | Resistor_THT:R_Axial_DIN0207_L6.3mm_D2.5mm_P7.62mm_Horizontal | ~
R4 | 820R | Resistor_THT:R_Axial_DIN0207_L6.3mm_D2.5mm_P7.62mm_Horizontal | ~
R5 | 820R | Resistor_THT:R_Axial_DIN0207_L6.3mm_D2.5mm_P7.62mm_Horizontal | ~
R6 | 820R | Resistor_THT:R_Axial_DIN0207_L6.3mm_D2.5mm_P7.62mm_Horizontal | ~
R7 | 820R | Resistor_THT:R_Axial_DIN0207_L6.3mm_D2.5mm_P7.62mm_Horizontal | ~
R8 | 820R | Resistor_THT:R_Axial_DIN0207_L6.3mm_D2.5mm_P7.62mm_Horizontal | ~
SW1 | SW_Push | dafx-kicad-lib:PinHeader_1x02_P2.54mm_Vertical | ~
R9 | 10k | Resistor_THT:R_Axial_DIN0207_L6.3mm_D2.5mm_P7.62mm_Horizontal | ~
SW2 | SW_Push | dafx-kicad-lib:PinHeader_1x02_P2.54mm_Vertical | ~
SW3 | SW_Push | dafx-kicad-lib:PinHeader_1x02_P2.54mm_Vertical | ~
SW4 | SW_Push | dafx-kicad-lib:PinHeader_1x02_P2.54mm_Vertical | ~
SW5 | SW_Push | dafx-kicad-lib:PinHeader_1x02_P2.54mm_Vertical | ~
D_S1 | LED | dafx-kicad-lib:LED_D5.0mm | ~
R19 | 820R | Resistor_THT:R_Axial_DIN0207_L6.3mm_D2.5mm_P7.62mm_Horizontal | ~
U4 | 74HC595 | Package_DIP:DIP-16_W7.62mm | http://www.ti.com/lit/ds/symlink/sn74hc595.pdf
D11 | LED | dafx-kicad-lib:LED_D5.0mm | ~
D12 | LED | dafx-kicad-lib:LED_D5.0mm | ~
D13 | LED | dafx-kicad-lib:LED_D5.0mm | ~
D14 | LED | dafx-kicad-lib:LED_D5.0mm | ~
D15 | LED | dafx-kicad-lib:LED_D5.0mm | ~
D16 | LED | dafx-kicad-lib:LED_D5.0mm | ~
D17 | LED | dafx-kicad-lib:LED_D5.0mm | ~
R21 | 820R | Resistor_THT:R_Axial_DIN0207_L6.3mm_D2.5mm_P7.62mm_Horizontal | ~
R22 | 820R | Resistor_THT:R_Axial_DIN0207_L6.3mm_D2.5mm_P7.62mm_Horizontal | ~
R23 | 820R | Resistor_THT:R_Axial_DIN0207_L6.3mm_D2.5mm_P7.62mm_Horizontal | ~
R24 | 820R | Resistor_THT:R_Axial_DIN0207_L6.3mm_D2.5mm_P7.62mm_Horizontal | ~
R25 | 820R | Resistor_THT:R_Axial_DIN0207_L6.3mm_D2.5mm_P7.62mm_Horizontal | ~
R26 | 820R | Resistor_THT:R_Axial_DIN0207_L6.3mm_D2.5mm_P7.62mm_Horizontal | ~
R27 | 820R | Resistor_THT:R_Axial_DIN0207_L6.3mm_D2.5mm_P7.62mm_Horizontal | ~
D_S2 | LED | dafx-kicad-lib:LED_D5.0mm | ~
R18 | 820R | Resistor_THT:R_Axial_DIN0207_L6.3mm_D2.5mm_P7.62mm_Horizontal | ~
R17 | 330R | Resistor_THT:R_Axial_DIN0207_L6.3mm_D2.5mm_P7.62mm_Horizontal | ~
R16 | 330R | Resistor_THT:R_Axial_DIN0207_L6.3mm_D2.5mm_P7.62mm_Horizontal | ~
K1 | FRT5 | Relay_THT:Relay_DPDT_FRT5 | https://www.elpro.org/de/index.php?controller=attachment&id_attachment=8663
Q1 | 2N3904 | Package_TO_SOT_THT:TO-92_Inline_Wide | https://www.fairchildsemi.com/datasheets/2N/2N3904.pdf
R15 | 1k | Resistor_THT:R_Axial_DIN0207_L6.3mm_D2.5mm_P7.62mm_Horizontal | ~
D9 | 1N914 | Diode_THT:D_DO-35_SOD27_P7.62mm_Horizontal | http://www.vishay.com/docs/85622/1n914.pdf
K2 | FRT5 | Relay_THT:Relay_DPDT_FRT5 | https://www.elpro.org/de/index.php?controller=attachment&id_attachment=8663
Q2 | 2N3904 | Package_TO_SOT_THT:TO-92_Inline_Wide | https://www.fairchildsemi.com/datasheets/2N/2N3904.pdf
R20 | 1k | Resistor_THT:R_Axial_DIN0207_L6.3mm_D2.5mm_P7.62mm_Horizontal | ~
D10 | 1N914 | Diode_THT:D_DO-35_SOD27_P7.62mm_Horizontal | http://www.vishay.com/docs/85622/1n914.pdf
K3 | FRT5 | Relay_THT:Relay_DPDT_FRT5 | https://www.elpro.org/de/index.php?controller=attachment&id_attachment=8663
Q3 | 2N3904 | Package_TO_SOT_THT:TO-92_Inline_Wide | https://www.fairchildsemi.com/datasheets/2N/2N3904.pdf
R29 | 1k | Resistor_THT:R_Axial_DIN0207_L6.3mm_D2.5mm_P7.62mm_Horizontal | ~
D19 | 1N914 | Diode_THT:D_DO-35_SOD27_P7.62mm_Horizontal | http://www.vishay.com/docs/85622/1n914.pdf
K4 | FRT5 | Relay_THT:Relay_DPDT_FRT5 | https://www.elpro.org/de/index.php?controller=attachment&id_attachment=8663
Q4 | 2N3904 | Package_TO_SOT_THT:TO-92_Inline_Wide | https://www.fairchildsemi.com/datasheets/2N/2N3904.pdf
R30 | 1k | Resistor_THT:R_Axial_DIN0207_L6.3mm_D2.5mm_P7.62mm_Horizontal | ~
D20 | 1N914 | Diode_THT:D_DO-35_SOD27_P7.62mm_Horizontal | http://www.vishay.com/docs/85622/1n914.pdf
K5 | FRT5 | Relay_THT:Relay_DPDT_FRT5 | https://www.elpro.org/de/index.php?controller=attachment&id_attachment=8663
Q5 | 2N3904 | Package_TO_SOT_THT:TO-92_Inline_Wide | https://www.fairchildsemi.com/datasheets/2N/2N3904.pdf
R31 | 1k | Resistor_THT:R_Axial_DIN0207_L6.3mm_D2.5mm_P7.62mm_Horizontal | ~
D21 | 1N914 | Diode_THT:D_DO-35_SOD27_P7.62mm_Horizontal | http://www.vishay.com/docs/85622/1n914.pdf
K6 | FRT5 | Relay_THT:Relay_DPDT_FRT5 | https://www.elpro.org/de/index.php?controller=attachment&id_attachment=8663
Q6 | 2N3904 | Package_TO_SOT_THT:TO-92_Inline_Wide | https://www.fairchildsemi.com/datasheets/2N/2N3904.pdf
R32 | 1k | Resistor_THT:R_Axial_DIN0207_L6.3mm_D2.5mm_P7.62mm_Horizontal | ~
D22 | 1N914 | Diode_THT:D_DO-35_SOD27_P7.62mm_Horizontal | http://www.vishay.com/docs/85622/1n914.pdf
Q7 | 2N3904 | Package_TO_SOT_THT:TO-92_Inline_Wide | https://www.fairchildsemi.com/datasheets/2N/2N3904.pdf
R33 | 1k | Resistor_THT:R_Axial_DIN0207_L6.3mm_D2.5mm_P7.62mm_Horizontal | ~
D23 | 1N914 | Diode_THT:D_DO-35_SOD27_P7.62mm_Horizontal | http://www.vishay.com/docs/85622/1n914.pdf
Q8 | 2N3904 | Package_TO_SOT_THT:TO-92_Inline_Wide | https://www.fairchildsemi.com/datasheets/2N/2N3904.pdf
R34 | 1k | Resistor_THT:R_Axial_DIN0207_L6.3mm_D2.5mm_P7.62mm_Horizontal | ~
D24 | 1N914 | Diode_THT:D_DO-35_SOD27_P7.62mm_Horizontal | http://www.vishay.com/docs/85622/1n914.pdf
PWR_IN1 | Barrel_Jack | Connector_Wire:SolderWire-0.5sqmm_1x02_P4.6mm_D0.9mm_OD2.1mm | ~
JI_1 | NYS2152/NYS215 | Connector_Audio:Jack_6.35mm_Neutrik_NMJ6HCD2_Horizontal | ~
JS_1 | NYS2152/NYS215 | Connector_Audio:Jack_6.35mm_Neutrik_NMJ6HCD2_Horizontal | ~
JR_2 | NYS2152/NYS215 | Connector_Audio:Jack_6.35mm_Neutrik_NMJ6HCD2_Horizontal | ~
JS_2 | NYS2152/NYS215 | Connector_Audio:Jack_6.35mm_Neutrik_NMJ6HCD2_Horizontal | ~
JR_3 | NYS2152/NYS215 | Connector_Audio:Jack_6.35mm_Neutrik_NMJ6HCD2_Horizontal | ~
JS_3 | NYS2152/NYS215 | Connector_Audio:Jack_6.35mm_Neutrik_NMJ6HCD2_Horizontal | ~
JR_4 | NYS2152/NYS215 | Connector_Audio:Jack_6.35mm_Neutrik_NMJ6HCD2_Horizontal | ~
JS_4 | NYS2152/NYS215 | Connector_Audio:Jack_6.35mm_Neutrik_NMJ6HCD2_Horizontal | ~
JR_5 | NYS2152/NYS215 | Connector_Audio:Jack_6.35mm_Neutrik_NMJ6HCD2_Horizontal | ~
JS_5 | NYS2152/NYS215 | Connector_Audio:Jack_6.35mm_Neutrik_NMJ6HCD2_Horizontal | ~
JS_6 | NYS2152/NYS215 | Connector_Audio:Jack_6.35mm_Neutrik_NMJ6HCD2_Horizontal | ~
JR_7 | NYS2152/NYS215 | Connector_Audio:Jack_6.35mm_Neutrik_NMJ6HCD2_Horizontal | ~
JS_7 | NYS2152/NYS215 | Connector_Audio:Jack_6.35mm_Neutrik_NMJ6HCD2_Horizontal | ~
JR_8 | NYS2152/NYS215 | Connector_Audio:Jack_6.35mm_Neutrik_NMJ6HCD2_Horizontal | ~
JS_8 | NYS2152/NYS215 | Connector_Audio:Jack_6.35mm_Neutrik_NMJ6HCD2_Horizontal | ~
JO_1 | NYS2152/NYS215 | Connector_Audio:Jack_6.35mm_Neutrik_NMJ6HCD2_Horizontal | ~
R28 | 820R | Resistor_THT:R_Axial_DIN0207_L6.3mm_D2.5mm_P7.62mm_Horizontal | ~
D18 | LED | dafx-kicad-lib:LED_D5.0mm | ~
JP1 | Jumper_NO_Small | Connector_PinHeader_2.54mm:PinHeader_1x02_P2.54mm_Vertical | ~
C5 | 100n | Capacitor_THT:C_Rect_L7.2mm_W2.5mm_P5.00mm_FKS2_FKP2_MKS2_MKP2 | ~
C6 | 100n | Capacitor_THT:C_Rect_L7.2mm_W2.5mm_P5.00mm_FKS2_FKP2_MKS2_MKP2 | ~
C7 | 100n | Capacitor_THT:C_Rect_L7.2mm_W2.5mm_P5.00mm_FKS2_FKP2_MKS2_MKP2 | ~
S1_1 | MountingHole_Pad | Connector_Wire:SolderWire-0.5sqmm_1x01_D0.9mm_OD2.1mm | ~
S1_2 | MountingHole_Pad | Connector_Wire:SolderWire-0.5sqmm_1x01_D0.9mm_OD2.1mm | ~
S2_2 | MountingHole_Pad | Connector_Wire:SolderWire-0.5sqmm_1x01_D0.9mm_OD2.1mm | ~
S2_1 | MountingHole_Pad | Connector_Wire:SolderWire-0.5sqmm_1x01_D0.9mm_OD2.1mm | ~
S3_1 | MountingHole_Pad | Connector_Wire:SolderWire-0.5sqmm_1x01_D0.9mm_OD2.1mm | ~
S3_2 | MountingHole_Pad | Connector_Wire:SolderWire-0.5sqmm_1x01_D0.9mm_OD2.1mm | ~
S4_1 | MountingHole_Pad | Connector_Wire:SolderWire-0.5sqmm_1x01_D0.9mm_OD2.1mm | ~
S4_2 | MountingHole_Pad | Connector_Wire:SolderWire-0.5sqmm_1x01_D0.9mm_OD2.1mm | ~
S5_1 | MountingHole_Pad | Connector_Wire:SolderWire-0.5sqmm_1x01_D0.9mm_OD2.1mm | ~
S5_2 | MountingHole_Pad | Connector_Wire:SolderWire-0.5sqmm_1x01_D0.9mm_OD2.1mm | ~
S6_1 | MountingHole_Pad | Connector_Wire:SolderWire-0.5sqmm_1x01_D0.9mm_OD2.1mm | ~
S6_2 | MountingHole_Pad | Connector_Wire:SolderWire-0.5sqmm_1x01_D0.9mm_OD2.1mm | ~
S7_1 | MountingHole_Pad | Connector_Wire:SolderWire-0.5sqmm_1x01_D0.9mm_OD2.1mm | ~
S7_2 | MountingHole_Pad | Connector_Wire:SolderWire-0.5sqmm_1x01_D0.9mm_OD2.1mm | ~
MIDI_OUT1 | DIN-5 | dafx-kicad-lib:MIDI-HEADER | https://www.bitsbox.co.uk/index.php?main_page=product_info&cPath=225_226_300&products_id=1601
R10 | 220R | Resistor_THT:R_Axial_DIN0207_L6.3mm_D2.5mm_P7.62mm_Horizontal | ~
GND1 | MountingHole_Pad | Connector_Wire:SolderWire-0.5sqmm_1x01_D0.9mm_OD2.1mm | ~
GND2 | MountingHole_Pad | Connector_Wire:SolderWire-0.5sqmm_1x01_D0.9mm_OD2.1mm | ~
PWR1 | MountingHole_Pad | Connector_Wire:SolderWire-0.5sqmm_1x01_D0.9mm_OD2.1mm | ~
PWR2 | MountingHole_Pad | Connector_Wire:SolderWire-0.5sqmm_1x01_D0.9mm_OD2.1mm | ~
TX1 | MountingHole_Pad | Connector_Wire:SolderWire-0.5sqmm_1x01_D0.9mm_OD2.1mm | ~
TX2 | MountingHole_Pad | Connector_Wire:SolderWire-0.5sqmm_1x01_D0.9mm_OD2.1mm | ~
MIDI_IN1 | DIN-5 | dafx-kicad-lib:MIDI-HEADER | https://www.bitsbox.co.uk/index.php?main_page=product_info&cPath=225_226_300&products_id=1601
U5 | 6N138 | Package_DIP:DIP-8_W7.62mm | http://www.onsemi.com/pub/Collateral/HCPL2731-D.pdf
R11 | 220R | Resistor_THT:R_Axial_DIN0207_L6.3mm_D2.5mm_P7.62mm_Horizontal | ~
D25 | 1N914 | Diode_THT:D_DO-35_SOD27_P7.62mm_Horizontal | http://www.vishay.com/docs/85622/1n914.pdf
R12 | 4k7 | Resistor_THT:R_Axial_DIN0207_L6.3mm_D2.5mm_P7.62mm_Horizontal | ~
R13 | 220R | Resistor_THT:R_Axial_DIN0207_L6.3mm_D2.5mm_P7.62mm_Horizontal | ~
RX1 | MountingHole_Pad | Connector_Wire:SolderWire-0.5sqmm_1x01_D0.9mm_OD2.1mm | ~
RX2 | MountingHole_Pad | Connector_Wire:SolderWire-0.5sqmm_1x01_D0.9mm_OD2.1mm | ~
D26 | 1N4001 | Diode_THT:D_DO-41_SOD81_P10.16mm_Horizontal | http://www.vishay.com/docs/88503/1n4001.pdf
U2 | LM7805_TO220 | Package_TO_SOT_THT:TO-220-3_Horizontal_TabDown | http://www.fairchildsemi.com/ds/LM/LM7805.pdf
JR_1 | NYS2152/NYS215 | Connector_Audio:Jack_6.35mm_Neutrik_NMJ6HCD2_Horizontal | ~
C8 | 200uF | Capacitor_THT:CP_Radial_D8.0mm_P2.50mm | ~
C9 | 100n | Capacitor_THT:C_Rect_L7.2mm_W2.5mm_P5.00mm_FKS2_FKP2_MKS2_MKP2 | ~
JP2 | GND/GNDA | Connector_PinHeader_2.54mm:PinHeader_1x02_P2.54mm_Vertical | ~
C10 | 200uF | Capacitor_THT:CP_Radial_D8.0mm_P2.50mm | ~
FB1 | Ferrite_Bead | 4MS:Ferrite_Bead_TH | ~
JR_6 | NYS2152/NYS215 | Connector_Audio:Jack_6.35mm_Neutrik_NMJ6HCD2_Horizontal | ~
C11 | 100n | Capacitor_THT:C_Rect_L7.2mm_W2.5mm_P5.00mm_FKS2_FKP2_MKS2_MKP2 | ~
D27 | 1N4001 | Diode_THT:D_DO-41_SOD81_P10.16mm_Horizontal | http://www.vishay.com/docs/88503/1n4001.pdf
GND3 | MountingHole_Pad | Connector_Wire:SolderWire-0.5sqmm_1x01_D0.9mm_OD2.1mm | ~
GNDA1 | MountingHole_Pad | Connector_Wire:SolderWire-0.5sqmm_1x01_D0.9mm_OD2.1mm | ~
K7 | G5V-1 | Relay_THT:Relay_SPDT_Omron_G5V-1 | http://omronfs.omron.com/en_US/ecb/products/pdf/en-g5v_1.pdf
K8 | G5V-1 | Relay_THT:Relay_SPDT_Omron_G5V-1 | http://omronfs.omron.com/en_US/ecb/products/pdf/en-g5v_1.pdf
SO_2 | MountingHole_Pad | Connector_Wire:SolderWire-0.5sqmm_1x01_D0.9mm_OD2.1mm | ~
SO_1 | MountingHole_Pad | Connector_Wire:SolderWire-0.5sqmm_1x01_D0.9mm_OD2.1mm | ~
GNDA3 | MountingHole_Pad | Connector_Wire:SolderWire-0.5sqmm_1x01_D0.9mm_OD2.1mm | ~
GNDA2 | MountingHole_Pad | Connector_Wire:SolderWire-0.5sqmm_1x01_D0.9mm_OD2.1mm | ~

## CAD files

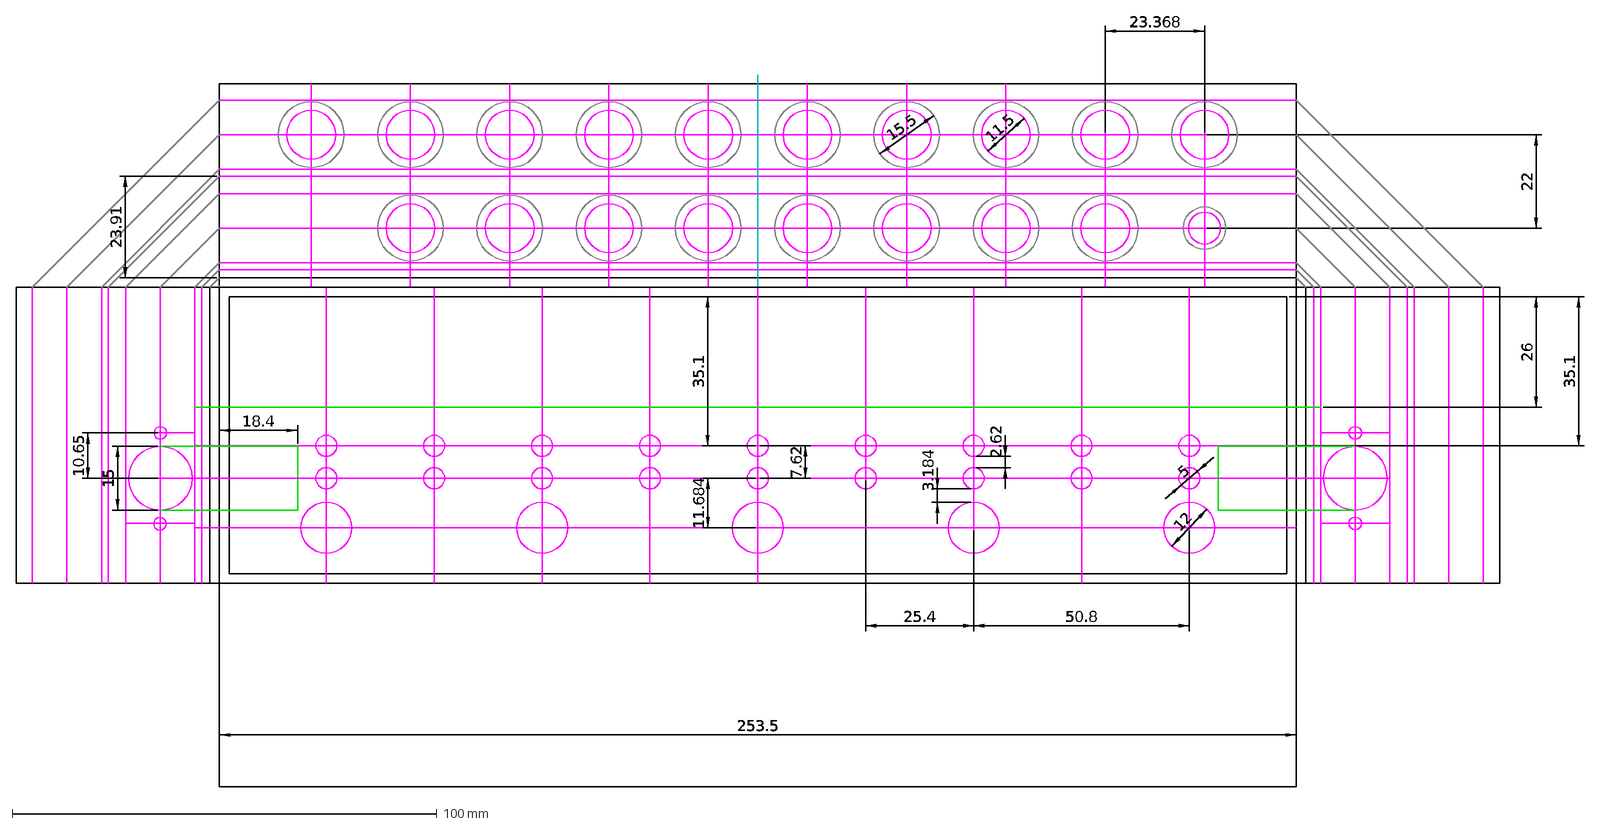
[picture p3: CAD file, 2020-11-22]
pcb.20200806/loop8-drilling-template.dxf
22
23.368
26
35.1
50.8
25.4
23.91
10.65
15
18.4
15.5
11.5
2.62
3.184
7.62
11.684
12
5
253.5

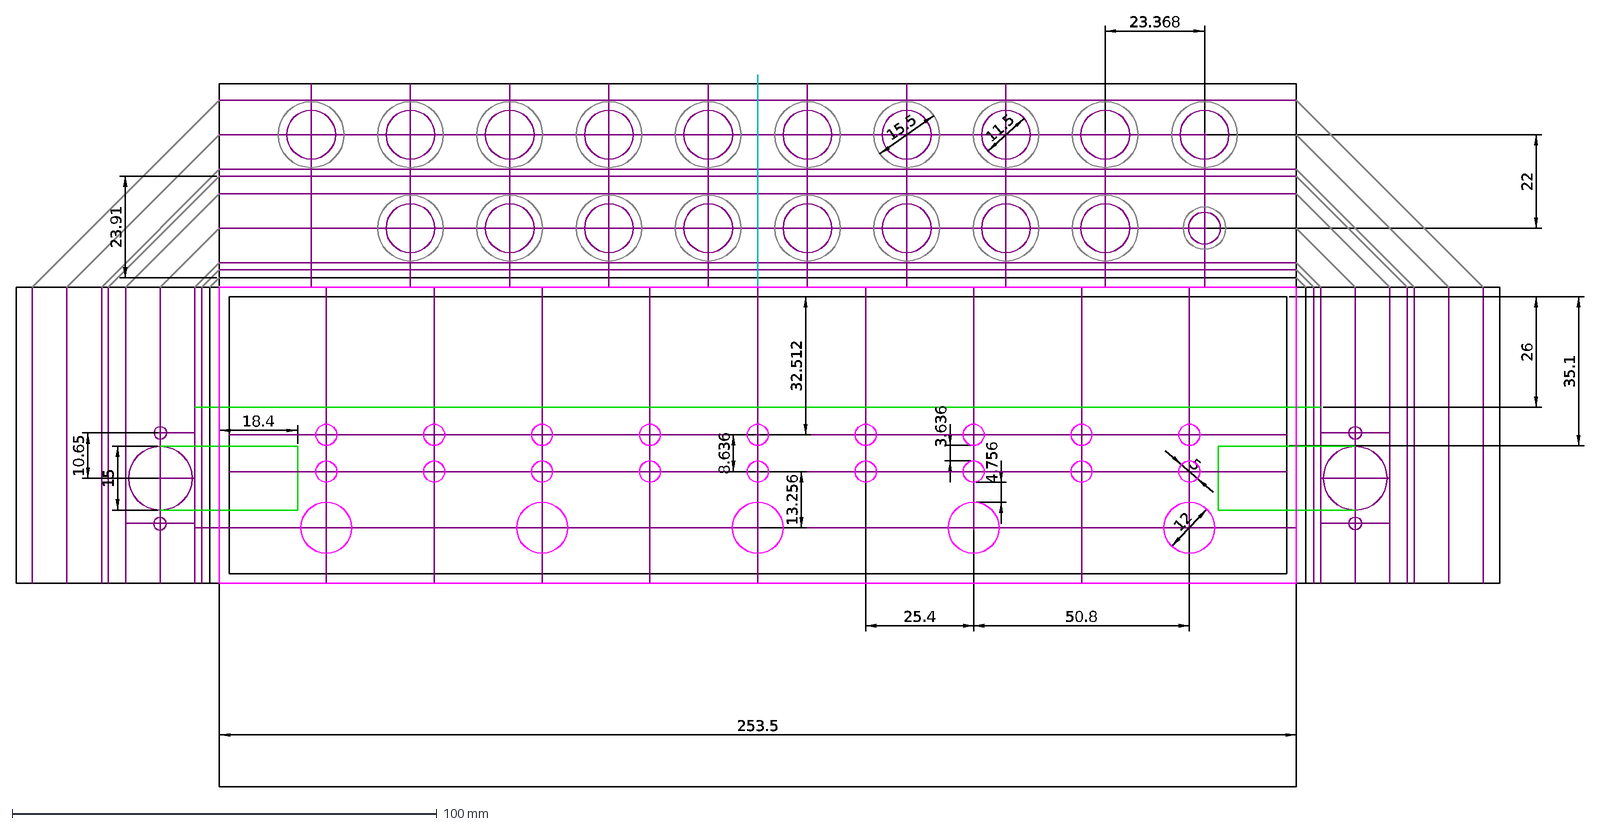
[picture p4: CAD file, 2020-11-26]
pcb.20201125/drilling_template.dxf
22
23.368
26
35.1
50.8
25.4
23.91
10.65
15
18.4
15.5
11.5
12
253.5
3.636
4.756
5
13.256
8.636
32.512

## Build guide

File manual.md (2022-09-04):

# Loopy LP8/LP422 Manual

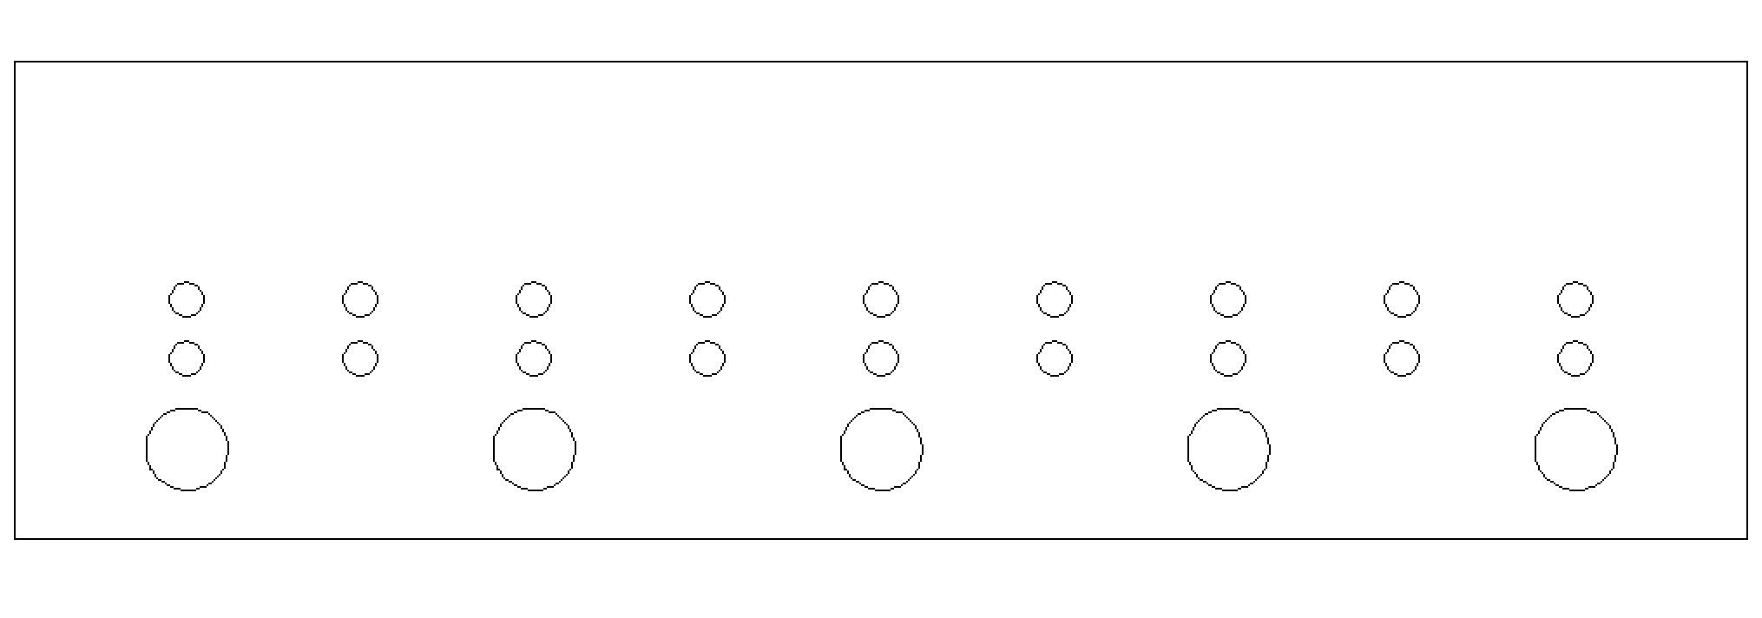
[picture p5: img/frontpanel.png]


The interface is built around 5 footswitches and 18 LED.

LED are divided into three groups:
- 2 LED on the right side to indicate the status
- 8 LED of the bottom strip to indicate whether a loop is engaged or not
- 8 LED of the top strip to indicate bank & preset

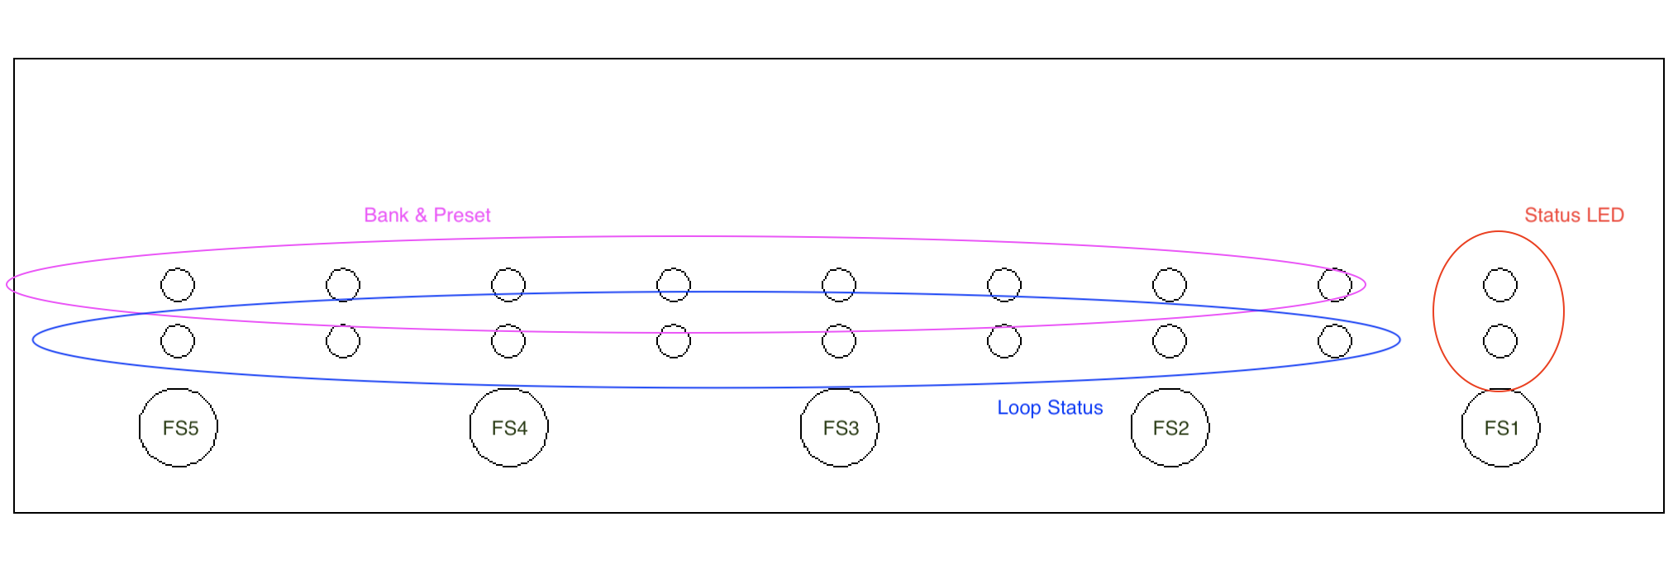
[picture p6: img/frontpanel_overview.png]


Loopy can be used in two modes:
- play
- preset

A very short video can be found below:

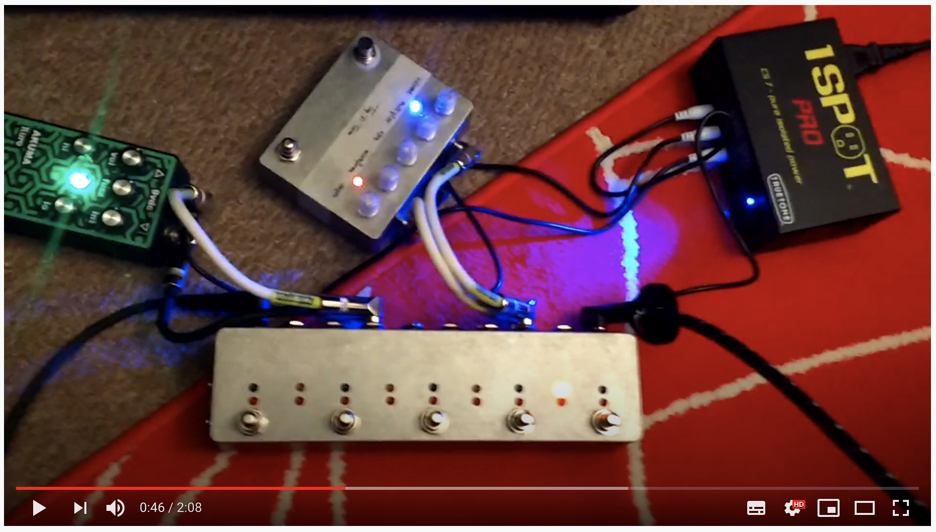
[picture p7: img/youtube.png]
Loopy Video 1 (https://www.youtube.com/watch?v=uNO9Kyx5gq8)


## Play Mode

In play mode, every loop can be directly accessed either pushing one footswitch, or two footswitch at the same time. The entire looper can be bypassed using the `Bypass` footswitch (`FS1`):

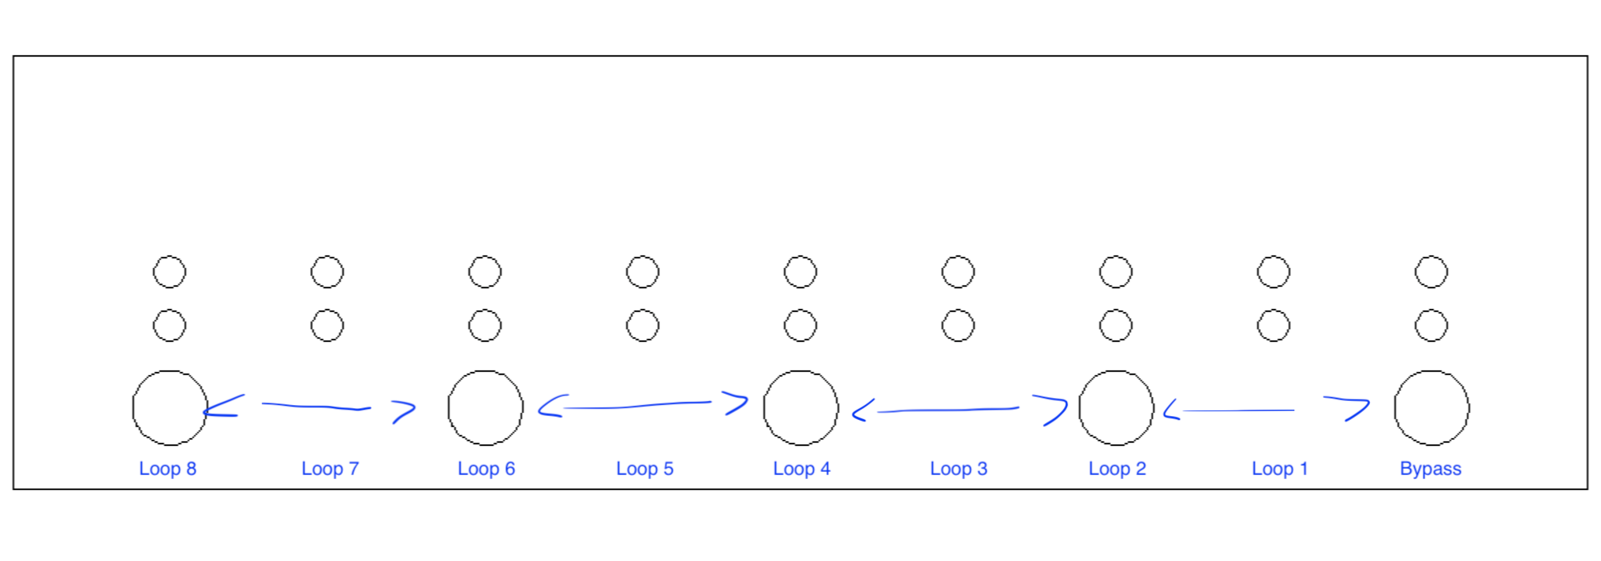
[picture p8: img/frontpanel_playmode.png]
Looper Play Mode Looper - Play Mode


## Preset Mode

To enter (and exit) the preset mode, hold the `FS1` for 2 seconds. 

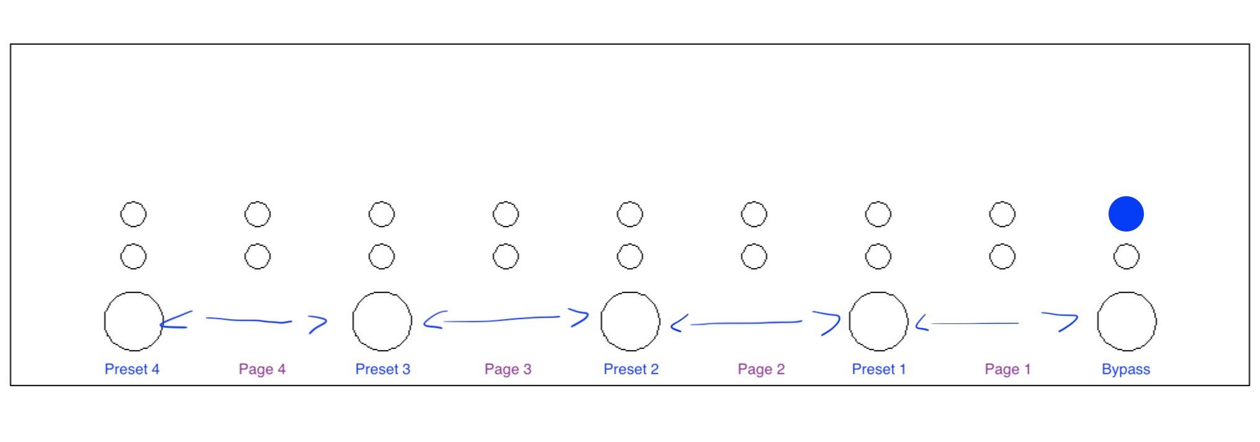
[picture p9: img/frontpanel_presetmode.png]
Looper Preset Mode Looper - Preset Mode


In preset mode, the first LED of the top strip will be ON to indicate the new mode.

When entering the preset mode LED on the first strip will start blinking to indicate the current page and preset. Loops will *not* immediately change their configuration when entering the preset mode to give the user the chance to select the right preset before before changing how the sound of the instrument is modified. 

The same behaviour is applied when moving across pages: no config is changed until a preset is confirmed.

Once a preset button is pressed, LED on the first strip will stop blinking and the LED on the second strip (and their associated loops) will switch on or off as programmed.

## MIDI

Since `v.2a`, MIDI support has been improved to:
- support Control Change commands
- configure MIDI channel

Version `v.1x` didn't support CC messages and was hardcoded to `Channel 1`. Instructions on how to update your firmware are available [here](./firmware.md).

### Midi Out

`MIDI Out` port is enabled when the looper is in `preset mode`. Program Change are sent to current channel using the table below:

| Page | Preset | Program Change |
| --- | --- | --- |
| 1 | 1 | 1 |
| 1 | 2 | 2 |
| 1 | 3 | 3 |
| 1 | 4 | 4 |
| 2 | 1 | 5 |
| 2 | 2 | 6 |
| 2 | 3 | 7 |
| 2 | 4 | 8 |
| 3 | 1 | 9 |
| 3 | 2 | 10 |
| 3 | 3 | 11 |
| 3 | 4 | 12 |
| 4 | 1 | 13 |
| 4 | 2 | 14 |
| 4 | 3 | 15 |
| 4 | 4 | 16 |

Since `v.2a`, it is possible to select the output channel. For version `v.1`, this value is fixed to `Channel 1`.

### MIDI Thru

Any data received in the `MIDI in` port is forwarded to the `MIDI out`, regardless of the operational mode of the looper.

### MIDI In

`MIDI In` port accepts Program Change (PC) commands on current channel.
Since `v.2a`, it is possible to select the input channel. For version `v.1`, this value is fixed to `Channel 1`.

Loopy contains a table of 128 memory locations that can be associated to the 128 MIDI PC commands.

To **store** a new preset, in `play mode`, hold `FS2` and `FS4` for 2 seconds.

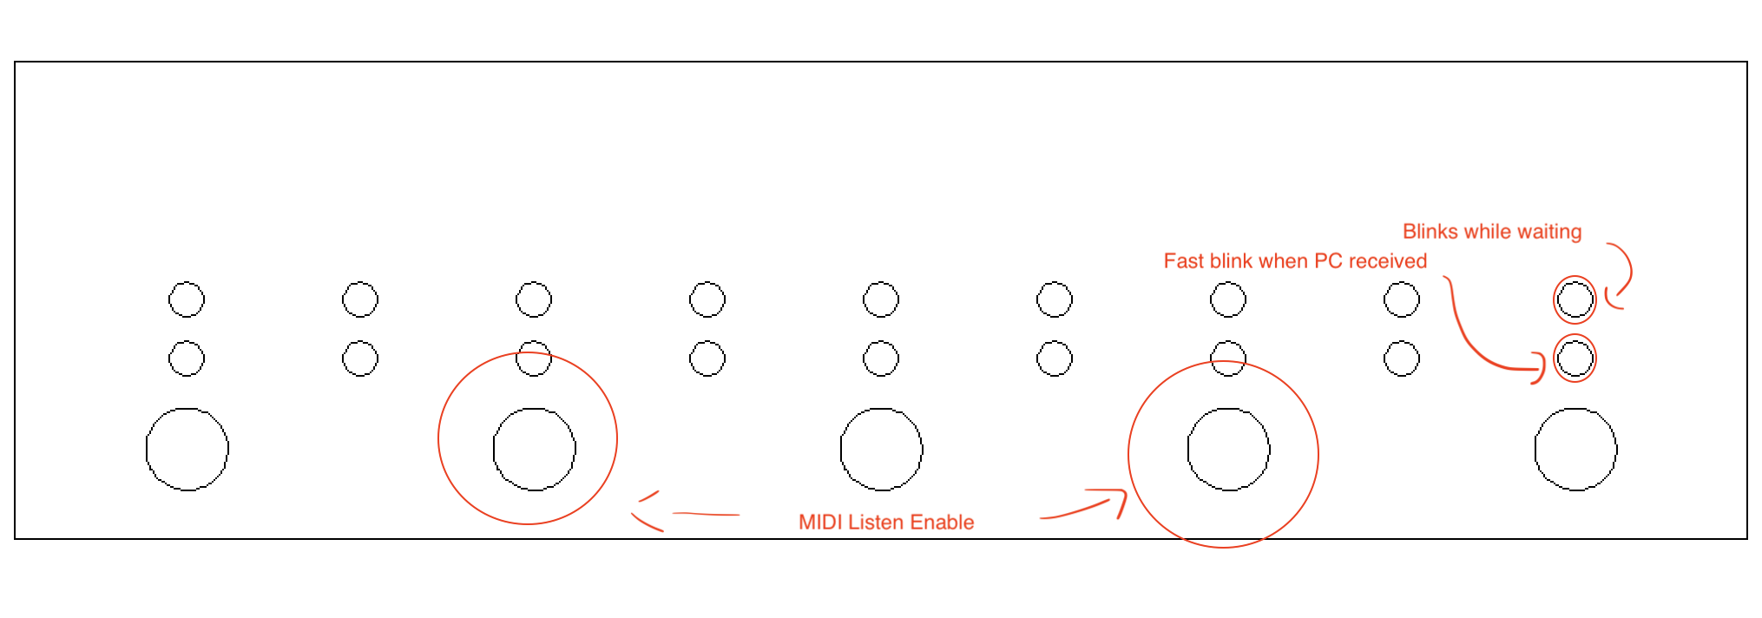
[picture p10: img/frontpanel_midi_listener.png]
Looper Preset Mode Looper - Enable MIDI Listener


Once the LED starts blinking, the looper will be waiting for a MIDI Program Change (PC) command on the current channel.

At this stage all the footswitch are still active to engage or disangege loops.

Once a PC is received, Loopy will store the combination of active loops in the associated PC memory location.

If you want to exit the `MIDI Listen Mode`, hold the FS1 (Bypass) pressed for 2 seconds (or alternative, hold the same combination used to enter the listening mode).

To **recall** a preset, send a PC command to Loopy when in `play mode`: configuration saved will be recalled and loops will engage/disengaged immediately. 

### MIDI Control Change

Since `v.2a`, Loopy is capable of understanding MIDI Control Change messages from the `MIDI In` port. These messages are used to toggle loops indipendently from an external source.

At the current stage, Loopy can only receive CC messages, but it cannot send them.

Differently then PC messages, CC messages contain both a message number and a value. Values in the range 0-63 will toggle **off** a loop, while values in the range 64-127 will toggle **on** a loop.

Loopy will listen a specifc range of CC messages: these are defined in the MIDI setup. The paragraph below explains how to setup MIDI channel and MIDI CC range.

If you want to chain multiple Loopy, you might need to change the CC Range in order to toggle loops on/off (an example in [this video](https://www.youtube.com/watch?v=EMZONCrGOTY)).
 
### MIDI Setup

To **enter** the MIDI Setup control panel hold  `FS3` and `FS5` for 2 seconds. This option is available only in `preset mode` in the `v.2a` firmware, and in `play mode` too since `v.2b`.

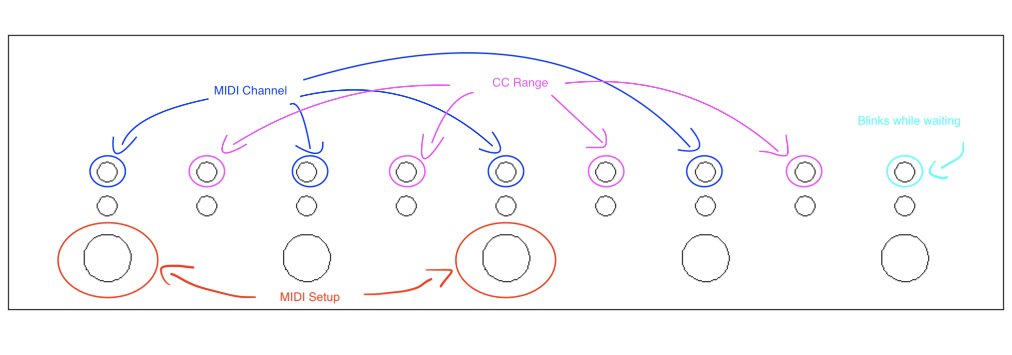
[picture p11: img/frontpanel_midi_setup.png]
Looper MIDI Setup Mode


Once in the MIDI setup, top line of LED allow to setup `MIDI Channel`, and `Control Change Range`.

Table below shows how to set the MIDI Channel (`x` for LED off, `o` for LED on):

| LED Combination | MIDI Channel |
| --- | --- |
| xxxx | Channel 1 |
| xxxo | Channel 2 |
| xxox | Channel 3 |
| xxoo | Channel 4 |
| xoxx | Channel 5 |
| xoxo | Channel 6 |
| xoox | Channel 7 |
| xooo | Channel 8 |
| oxxx | Channel 9 |
| oxxo | Channel 10 |
| oxox | Channel 11 |
| oxoo | Channel 12 |
| ooxx | Channel 13 |
| ooxo | Channel 14 |
| ooox | Channel 15 |
| oooo | Channel 16 (default) |

Table below shows how to set the MIDI Control Change range (`x` for LED off, `o` for LED on):

| LED Combination | MIDI CC Range |
| --- | --- |
| xxxx | 0-7 |
| xxxo | 8-13 |
| xxox | 14-23 |
| xxoo | 24-31 |
| xoxx | 32-39 |
| xoxo | 40-47 |
| xoox | 48-55 |
| xooo | 56-63 |
| oxxx | 64-71 |
| oxxo | 72-79 |
| oxox | 80-87 (default) |
| oxoo | 88-95 |
| ooxx | 96-103 |
| ooxo | 104-111 |
| ooox | 112-119 |
| oooo | 120-127 |

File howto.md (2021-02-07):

# How To Build Loopy

Loopy is a medium complexity project for the occasional DIY-er, while it should be fairly straightforward for an avid one.

##  Step 1: Drilling

In my opinion, the hardest part of the build process is drilling the enclosure, due to the large number of holes.

My method is the following:
- print the drilling template specific for your PCB
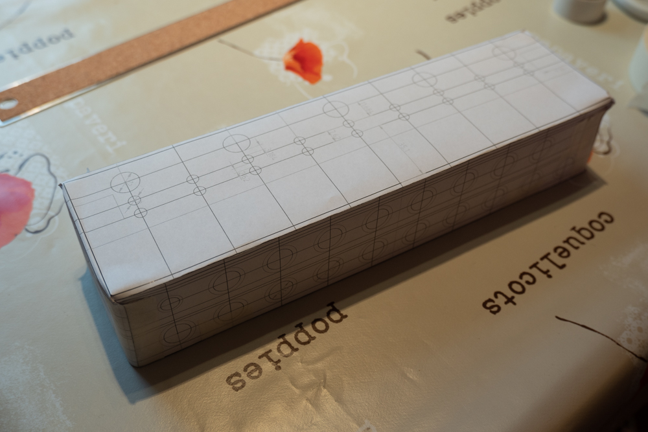
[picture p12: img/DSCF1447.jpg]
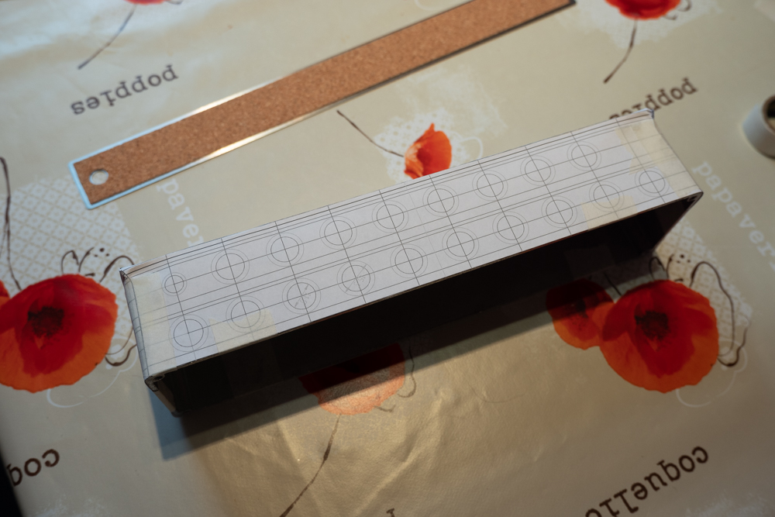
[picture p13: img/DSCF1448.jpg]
- attach the drilling template to the enclosure **being as precise as you can**    

- use a good quality center punch to set a drilling guide for each hole. It is very important especially for the holes on the front panel
- drill every hole with a pilot bit (either 2mm, 2.5mm or 3mm works, but I usually tend towards the smaller size)
- work your way up through the holes up to the right size for your components, but don't overdrill the front panel 5mm LED holes
- slightly overdrill the holes on the backpanel, as this will make easier to insert the PCB at the end
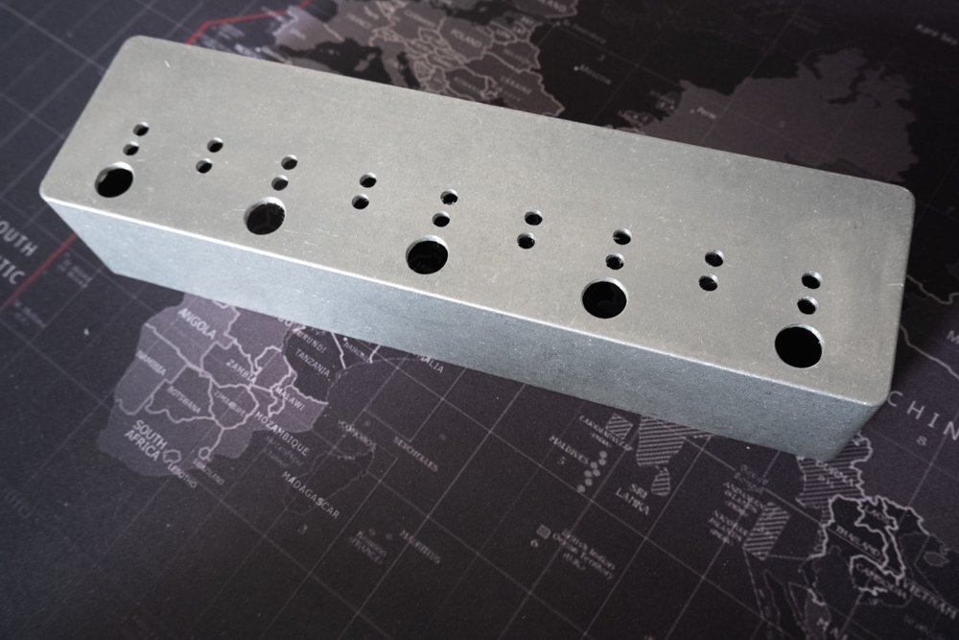
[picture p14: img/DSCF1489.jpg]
- clean the enclosure and get ready for soldering 

## Step 2: Soldering

**Important**: don't solder any LED on the board, as otherwise you won't be able to box up your project.

All the jacks are mounted on the two boards, so I suggest to work your way up into the enclosure in the following order:
- solder wires to all the footswitches and set them in place inside the enclosure: use a reasonable length that will allow you to solder the other end on the main board
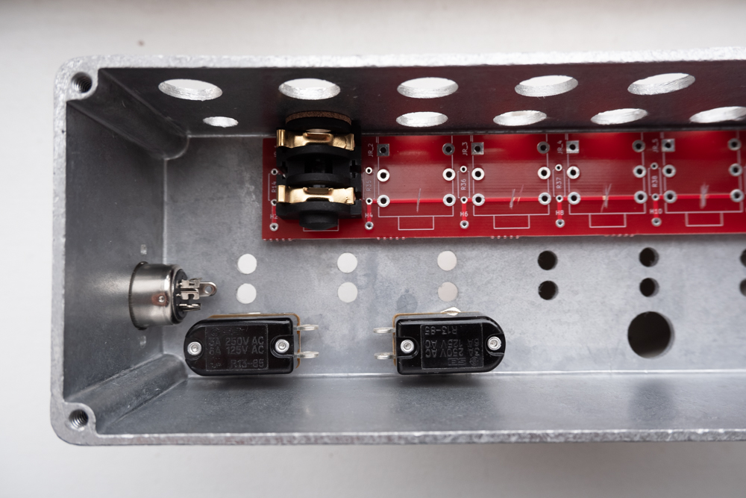
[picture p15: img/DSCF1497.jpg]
Footswitch


- solder all the components on the small board, including all the wires that will connect to the main board and the MIDI sockets
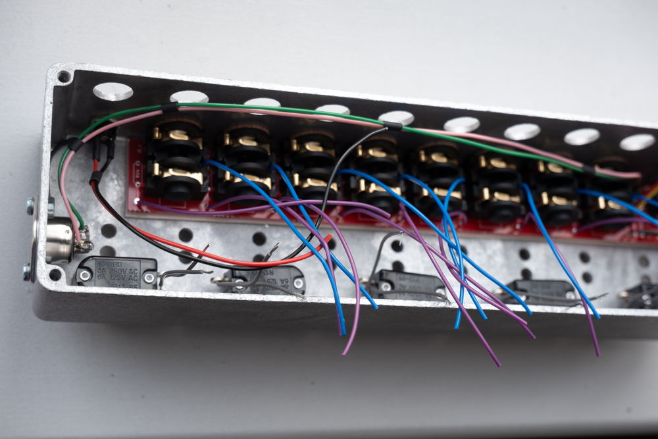
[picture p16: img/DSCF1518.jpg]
Small Board

- install both midi jacks and power socket into the enclosure
- install the small PCB on the bottom of the enclosure, screwing all the jacks into the right place. If you want to be extra sure none of the solder joins touches the enclosure, trim them the best you can and install a small plastic sheet at the bottom of the enclosure, secured with double-sided tape (not mandatory)
- solder the midi socket, trimming the wires to avoid them being loose in the enclosure.
- solder all the components on the main board, but **don't solder the LED**
Main Board

- solder all the connection wires between the two boards, including all the footswitches and the power socket
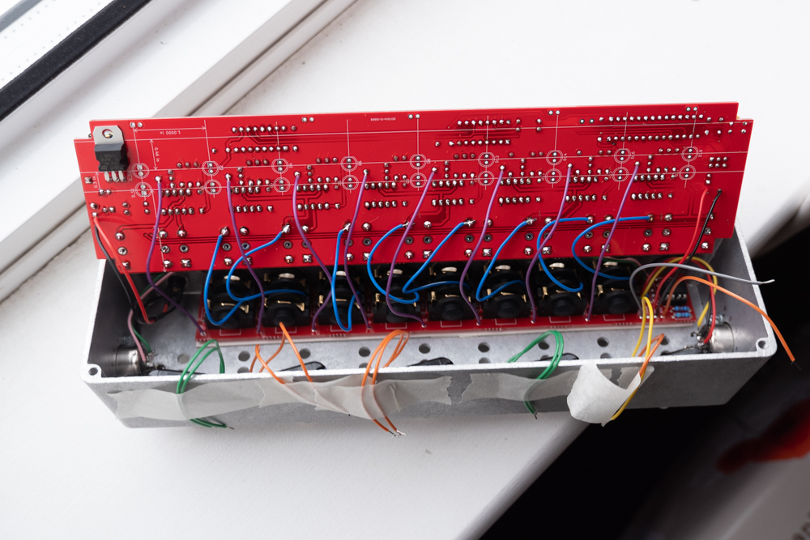
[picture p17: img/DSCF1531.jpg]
Power Up


- **you should now be able to power up your project**, and check the activation of the all the relays, as well that all the voltages are correct (especially in and out of the voltage regulator)

I have uploaded a [small video on YouTube](https://www.youtube.com/watch?v=tt-ZAocfp6Q) that shows how the board should look like at this stage.

## Step 3: Finish it up & LED installation

If you got at this stage of the build, you are ready for the tricky part: the installation of the LED.
You need to purchase LED with long leads (so the super common one available on eBay might not do): as you might have noticed, LED will be soldered into the main board and mounted inside the 5mm hole on the front panel directly.

The following steps should get you over the finishing line:
- if your project powers up correctly and you can hear the "click" of the relay when you use the footswitch, you know you are on track
- install -- without soldering -- all the LED into the main board: silkscreen should help you get them in the correct orientation: ideally they should light up as (and when) expected by the operational mode your looper is into
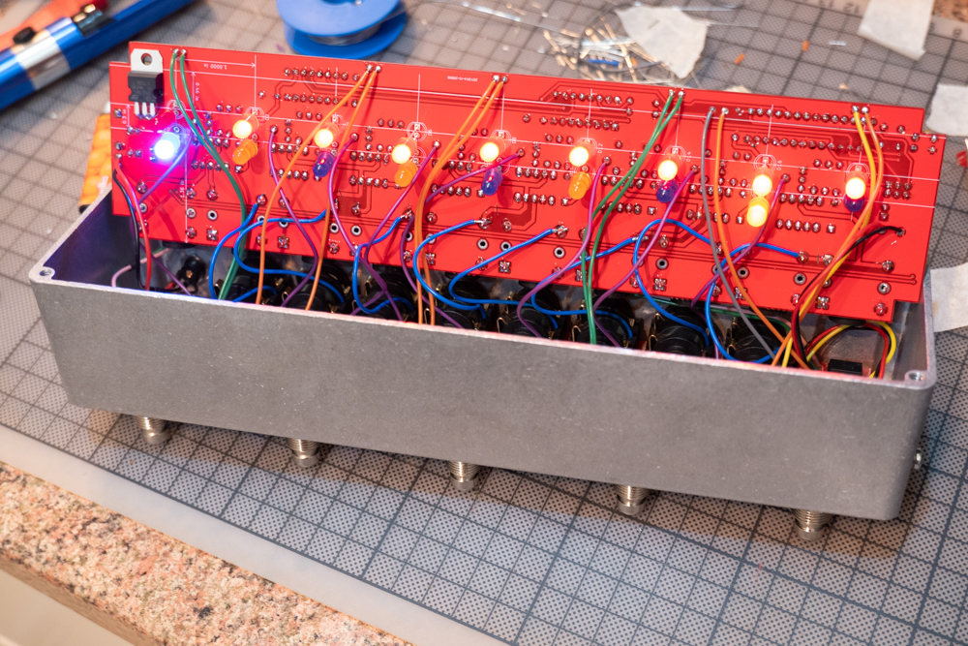
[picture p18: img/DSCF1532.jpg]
LED Test


- check all the LED light correctly triggering all the features (check the [manual](./manual.md) for more info)
- lock all the leads in place using small pieces of masking tapes, but don't bend the leads: this will allow you to rotate the board into its place without dropping all the LED out of the board
- tight the nut of a few jack socket so that the main board is in place
- one by one, release LED from their masking tape and make sure they finds the right hole on the front panel: might take a bit of time, so be patient
- you should be able now to power up the project and do another rundown before soldering all the LED (I strongly suggestt you do this!)
- if you are happy everything is working as expected, you can start soldering one by one all the LED and remove the excess for each lead (shouldn't be much)
- tight all the sockets
- job done, enjoy your programmable looper! :-)

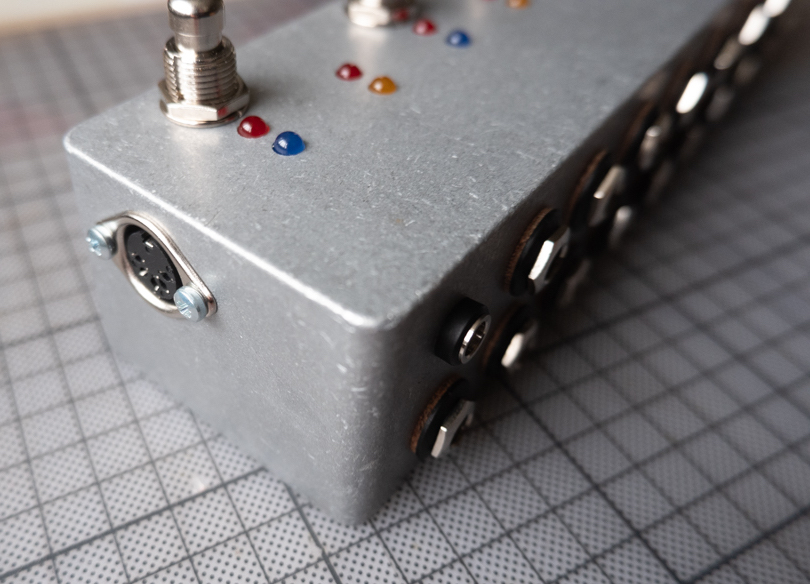
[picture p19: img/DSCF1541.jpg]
Looper Midi Socket

Looper

### Components Guide

#### Firmware 

| Firmware | Description |
| --- | --- |
| v1 | Original version, burnt into the first batch of chips |
| v1b | Use MIDI out as MIDI Thru; Better timing in button debouncing |
| v2(a, b) | MIDI Control Change + MIDI Control Panel |

#### Firmware Compatibility Matrix

| Firmware \ PCB  | PCB.20200806 | PCB.20201125 |
| --- | --- | --- |
| v1 | Yes | Yes |
| v1b | Yes | Yes |
| v2a | Yes | Yes |
| v2b | Yes | Yes |

#### Relays

Loopy uses miniaturised signal relays. Some of the possible options are:

- Zettler AZ850-5
- NEC EA2-5NU/EA2-5NJ (other brands produce this item with the same name)
- Fujitsu A-5W-K
- Panasonic/NAIS TQ2-5V

Some of these models are discontinued, but any other signal relay with the same pinout will work just fine. I have uploaded a few datasheets for consultation in the `datasheets` folder.

#### LED

Any 5mm LED work in this project, but you want to be careful with the type you use and the resistors you couple with it. 

I have personally used 400mcd LED like the one [here](https://www.switchelectronics.co.uk/blue-5mm-led-diffused-400mcd-30) with an 820R resistor, however you *must* use a larger resistor value with high brightness LED, or you'll end up with a front panel too bright to be usable.

I strongly suggest to buy decent quality one and test all of them before mouting: undoing the LED installation can be a painful job.

#### Audio Jack

I suggest to use the REAN/Neutrik NYS2152, but the REAN/Neutrik NYS215 works too (stereo version): PCB is designed around this footprint and the schematic uses stereo jacks, so an additional (unused, unconnected) hole is available on the PCB. this should give you some flexibility in the sourcing of the part.
Drawing diagram for these jacks is in the `datasheets` folder.

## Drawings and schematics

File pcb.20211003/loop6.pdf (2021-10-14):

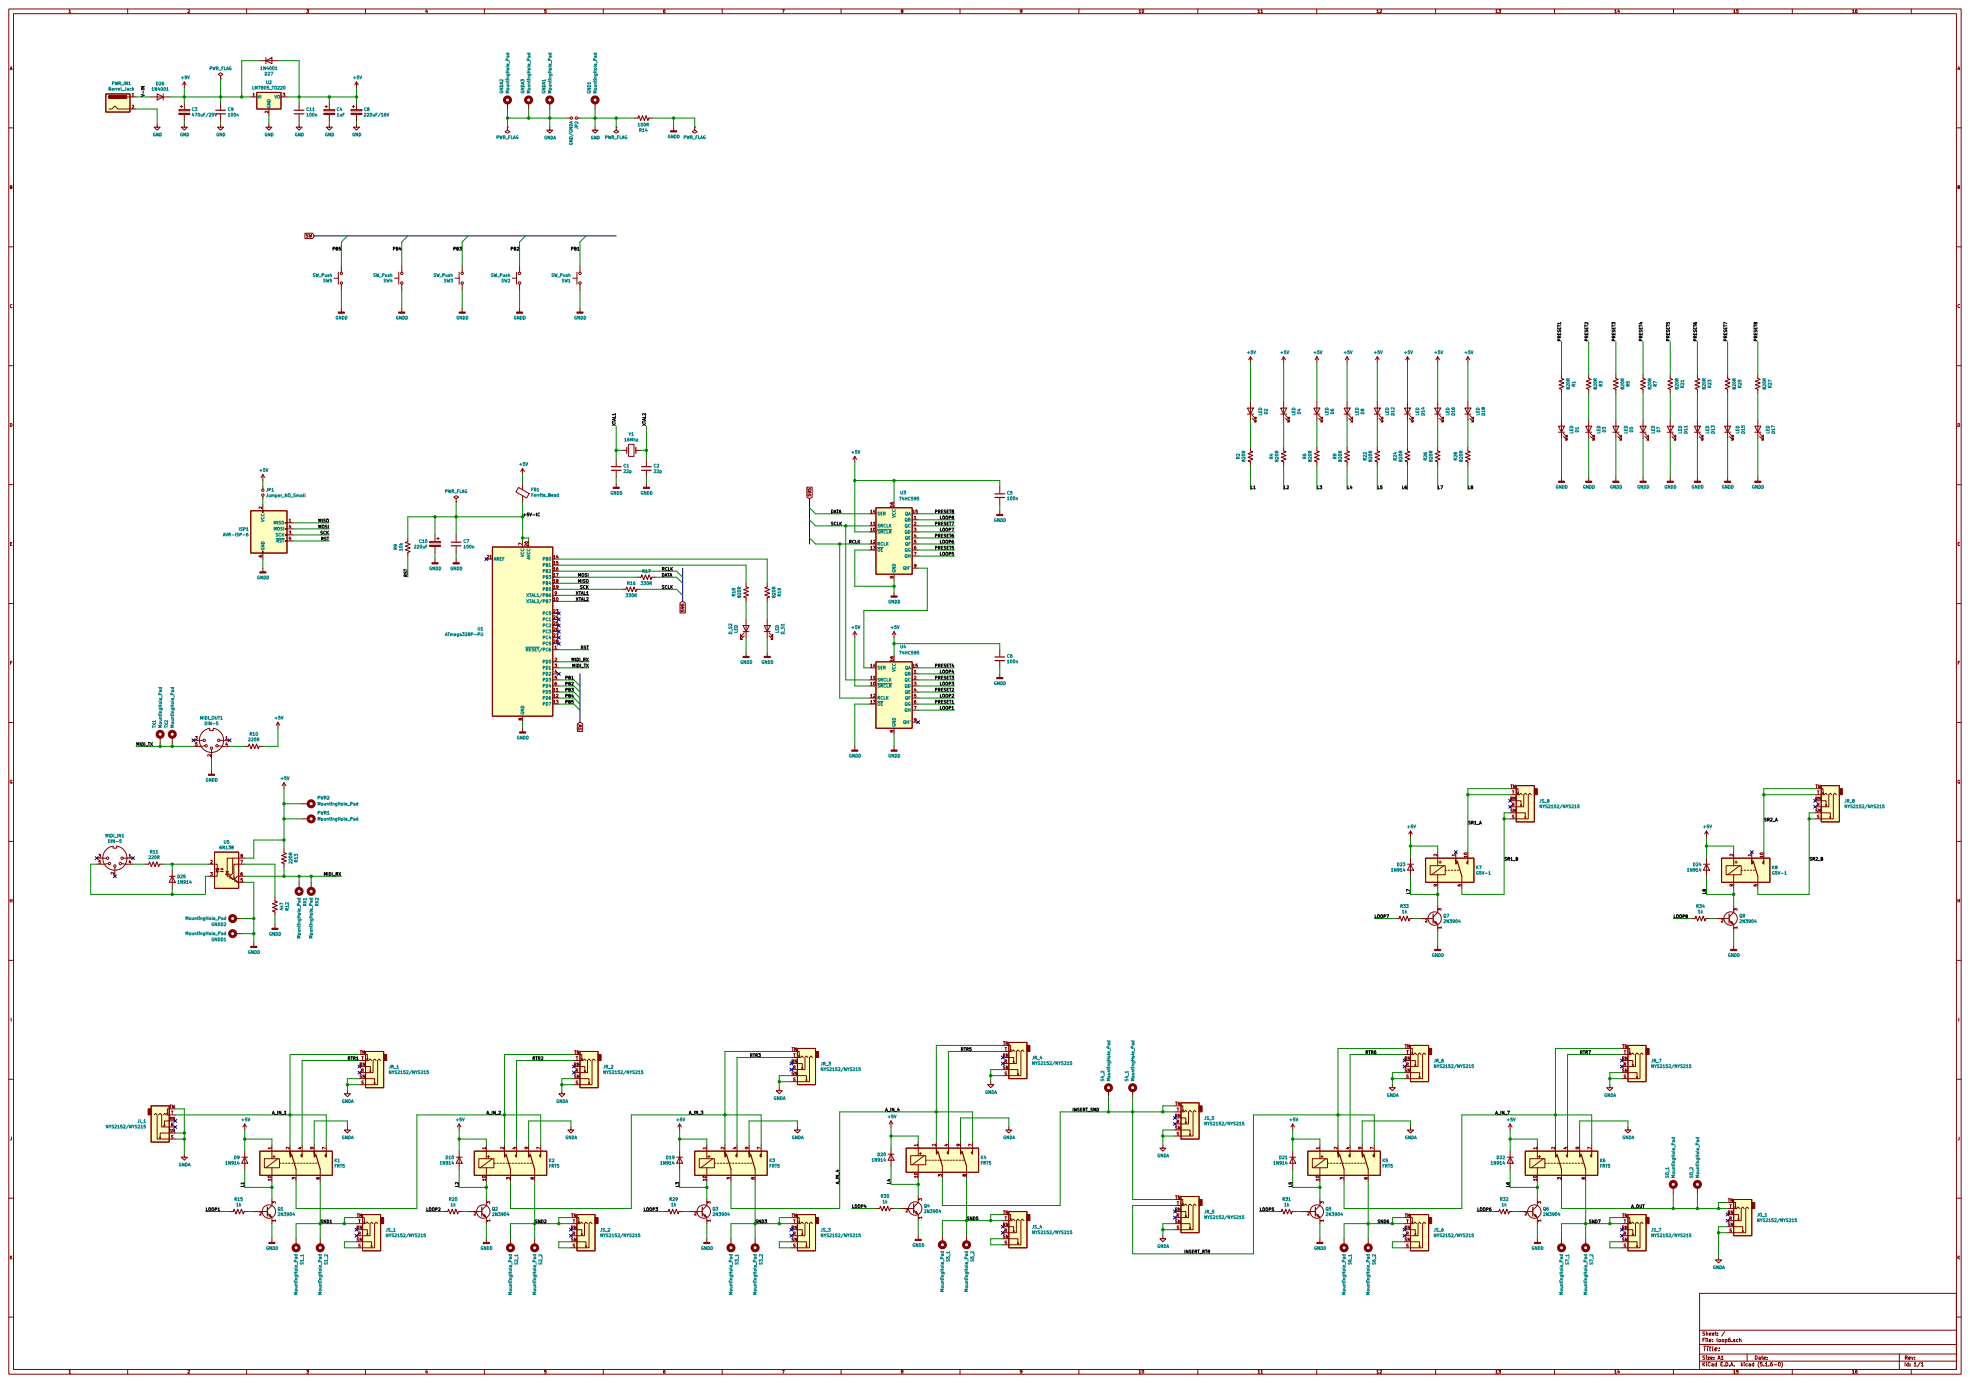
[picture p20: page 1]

2 SCK 3 MOSI 4 RST 5 GND

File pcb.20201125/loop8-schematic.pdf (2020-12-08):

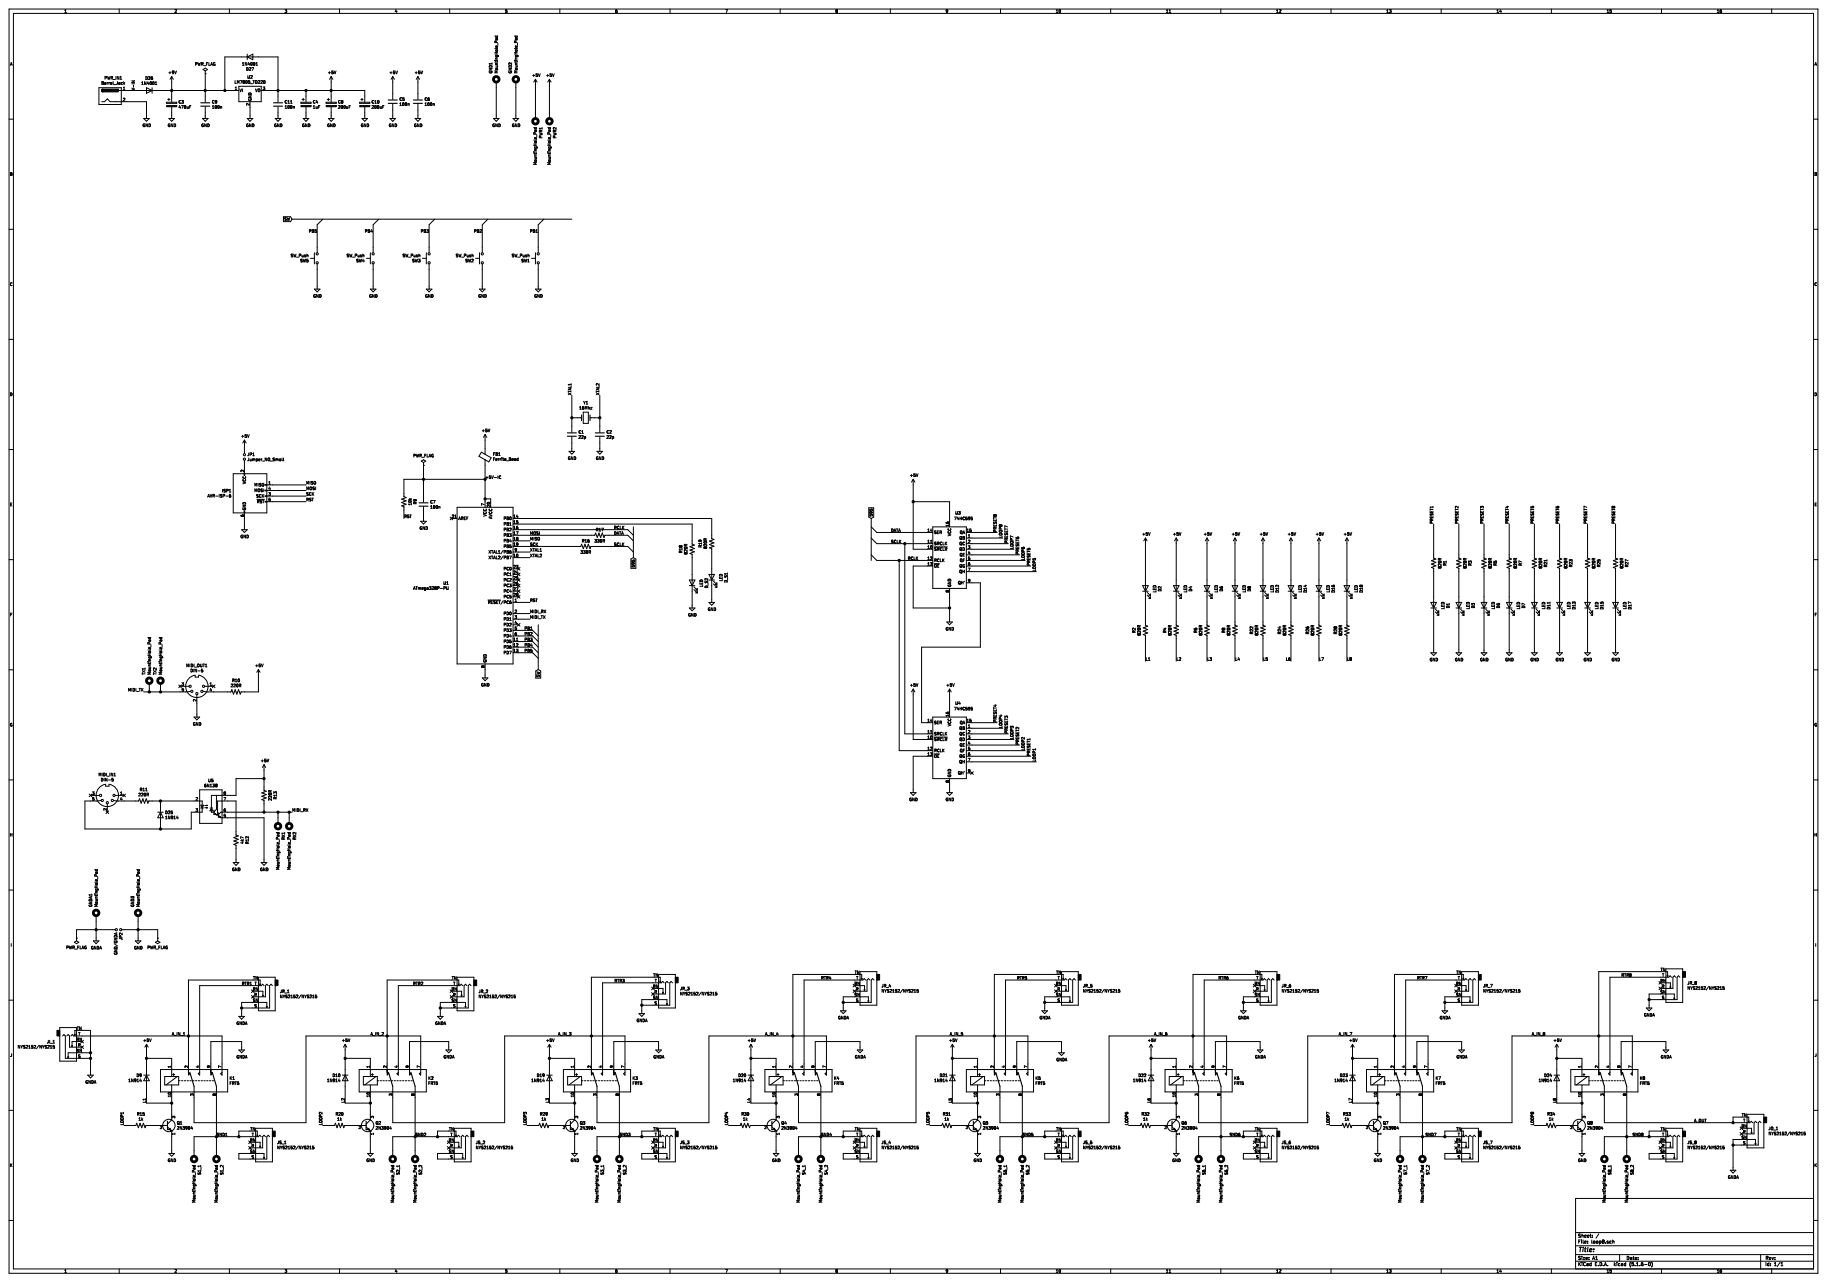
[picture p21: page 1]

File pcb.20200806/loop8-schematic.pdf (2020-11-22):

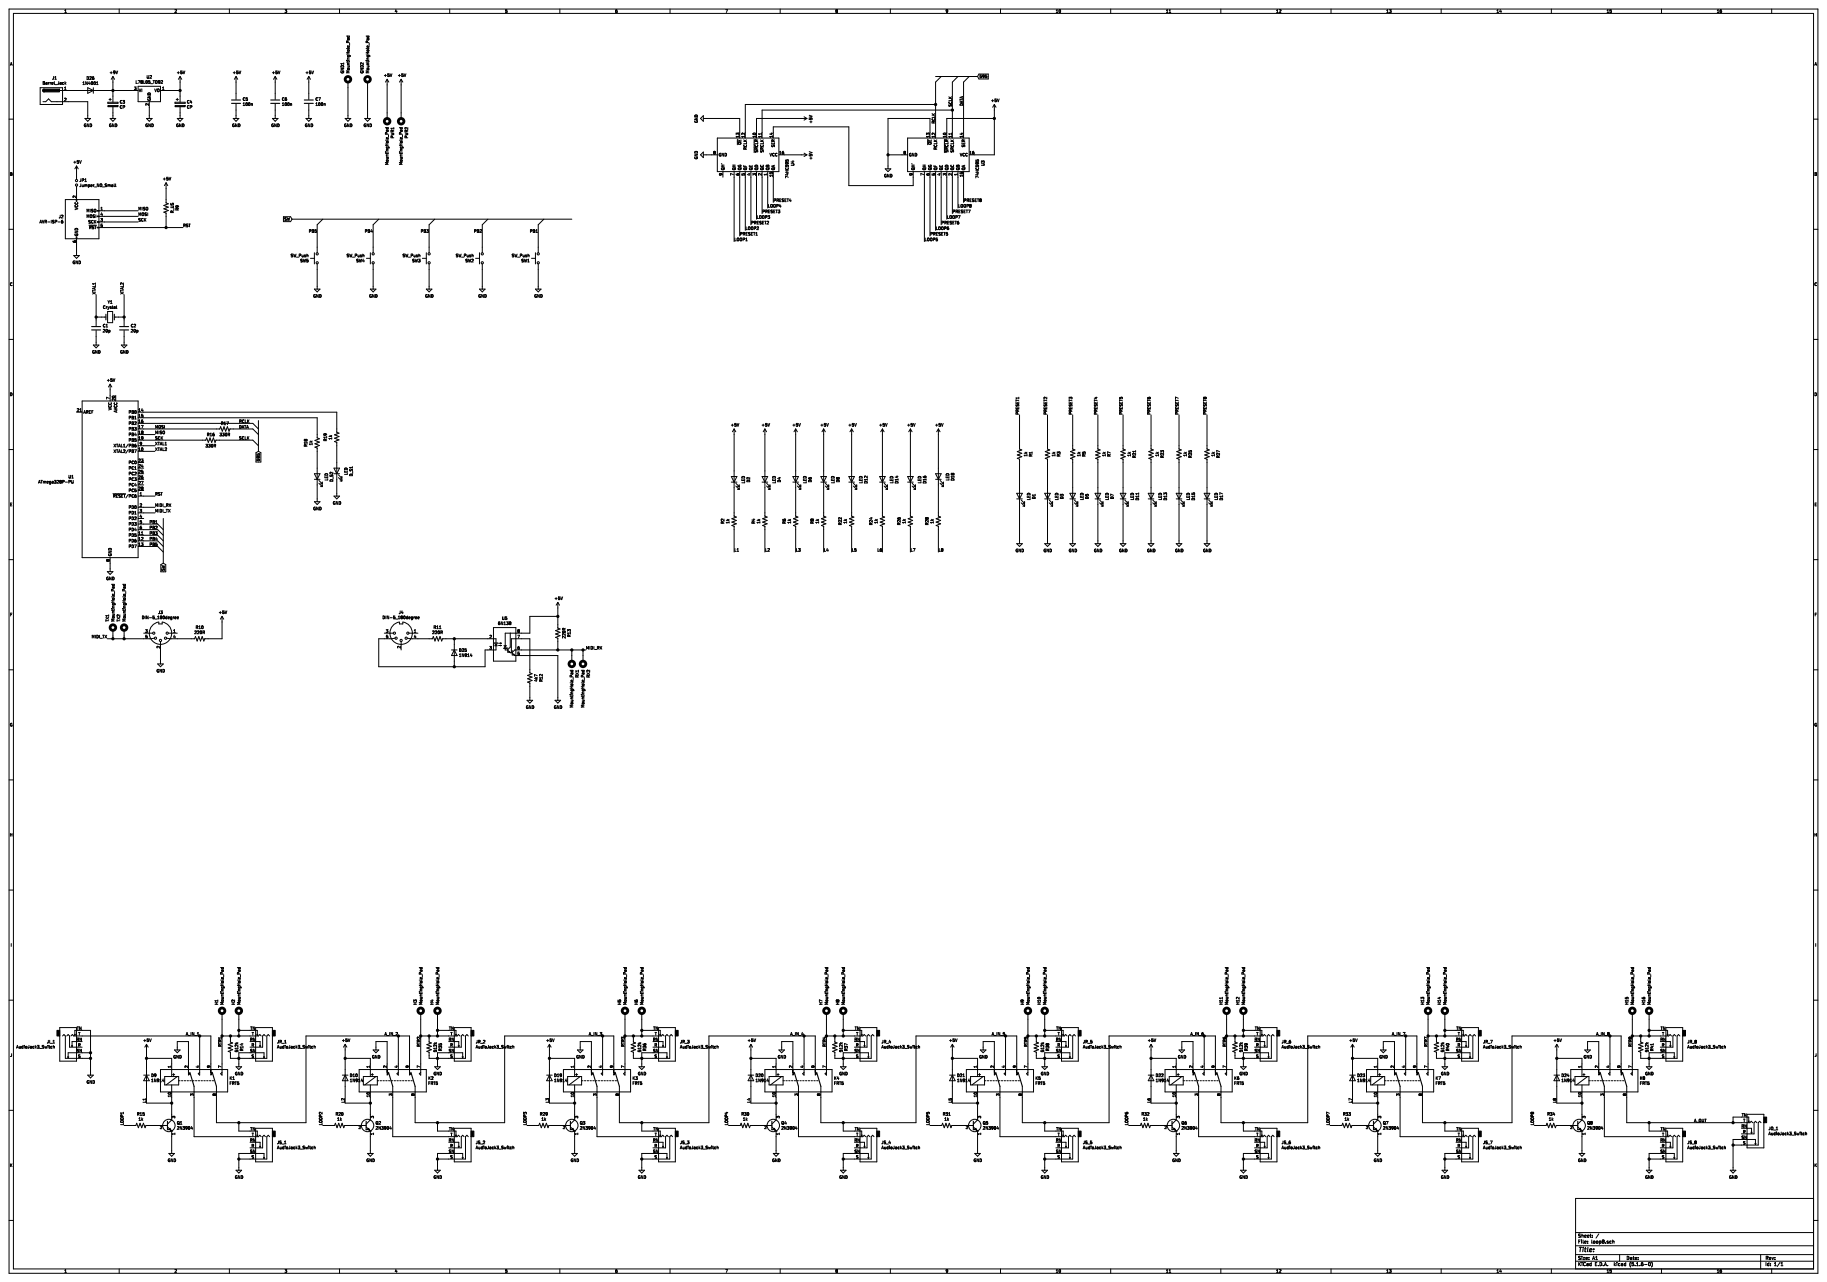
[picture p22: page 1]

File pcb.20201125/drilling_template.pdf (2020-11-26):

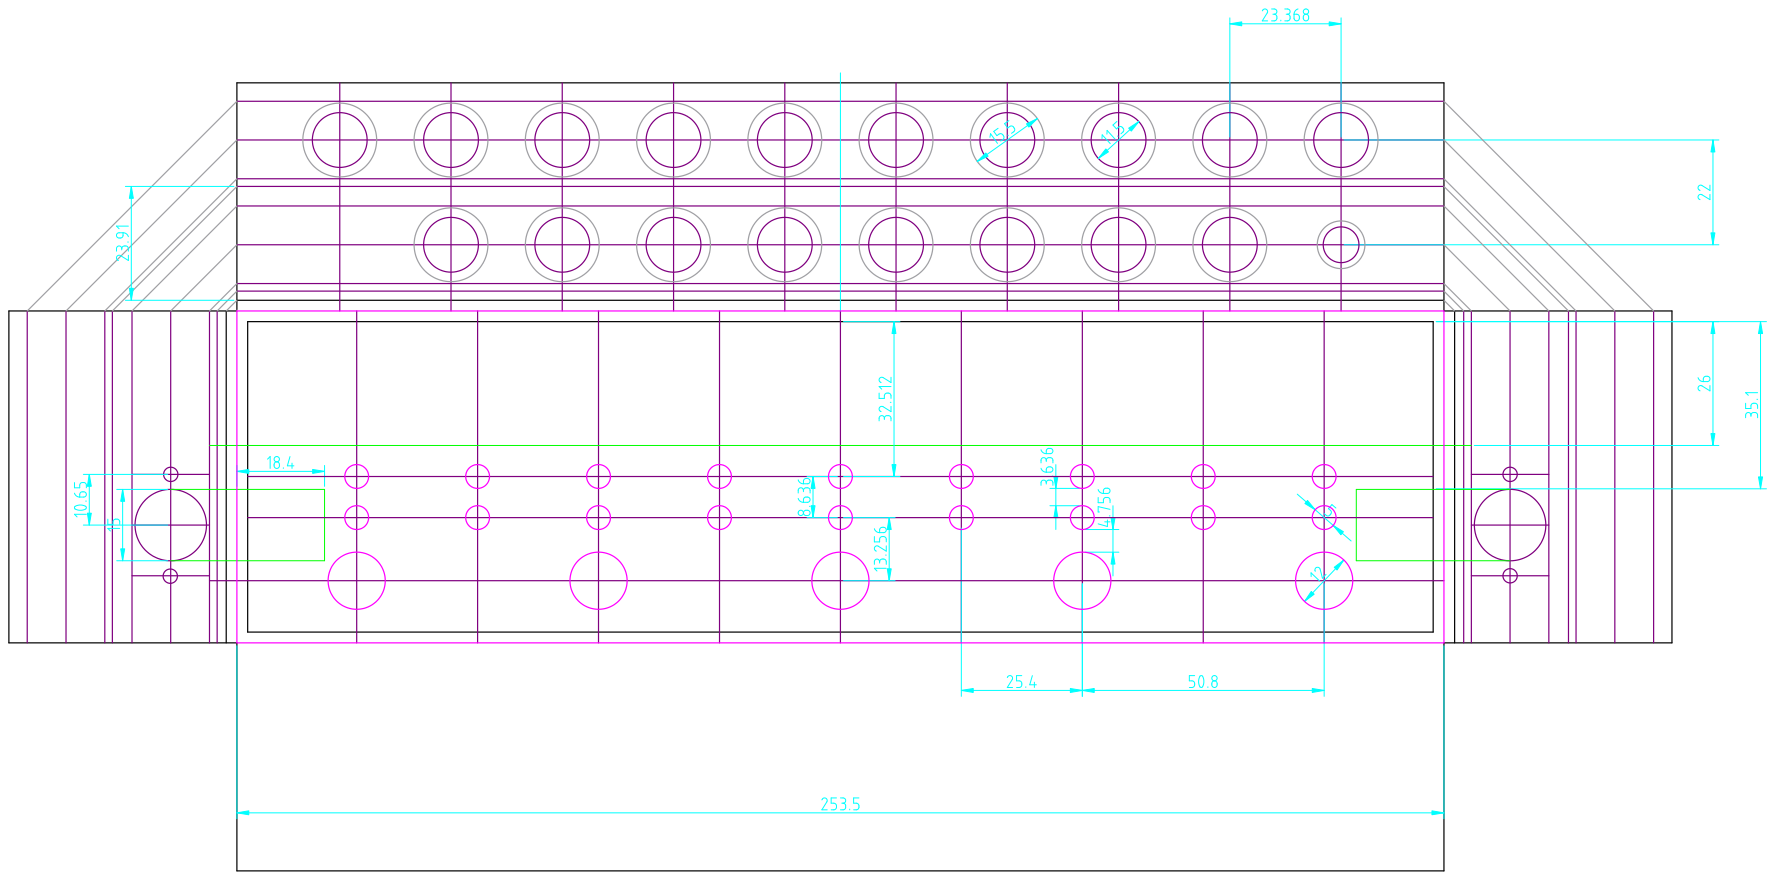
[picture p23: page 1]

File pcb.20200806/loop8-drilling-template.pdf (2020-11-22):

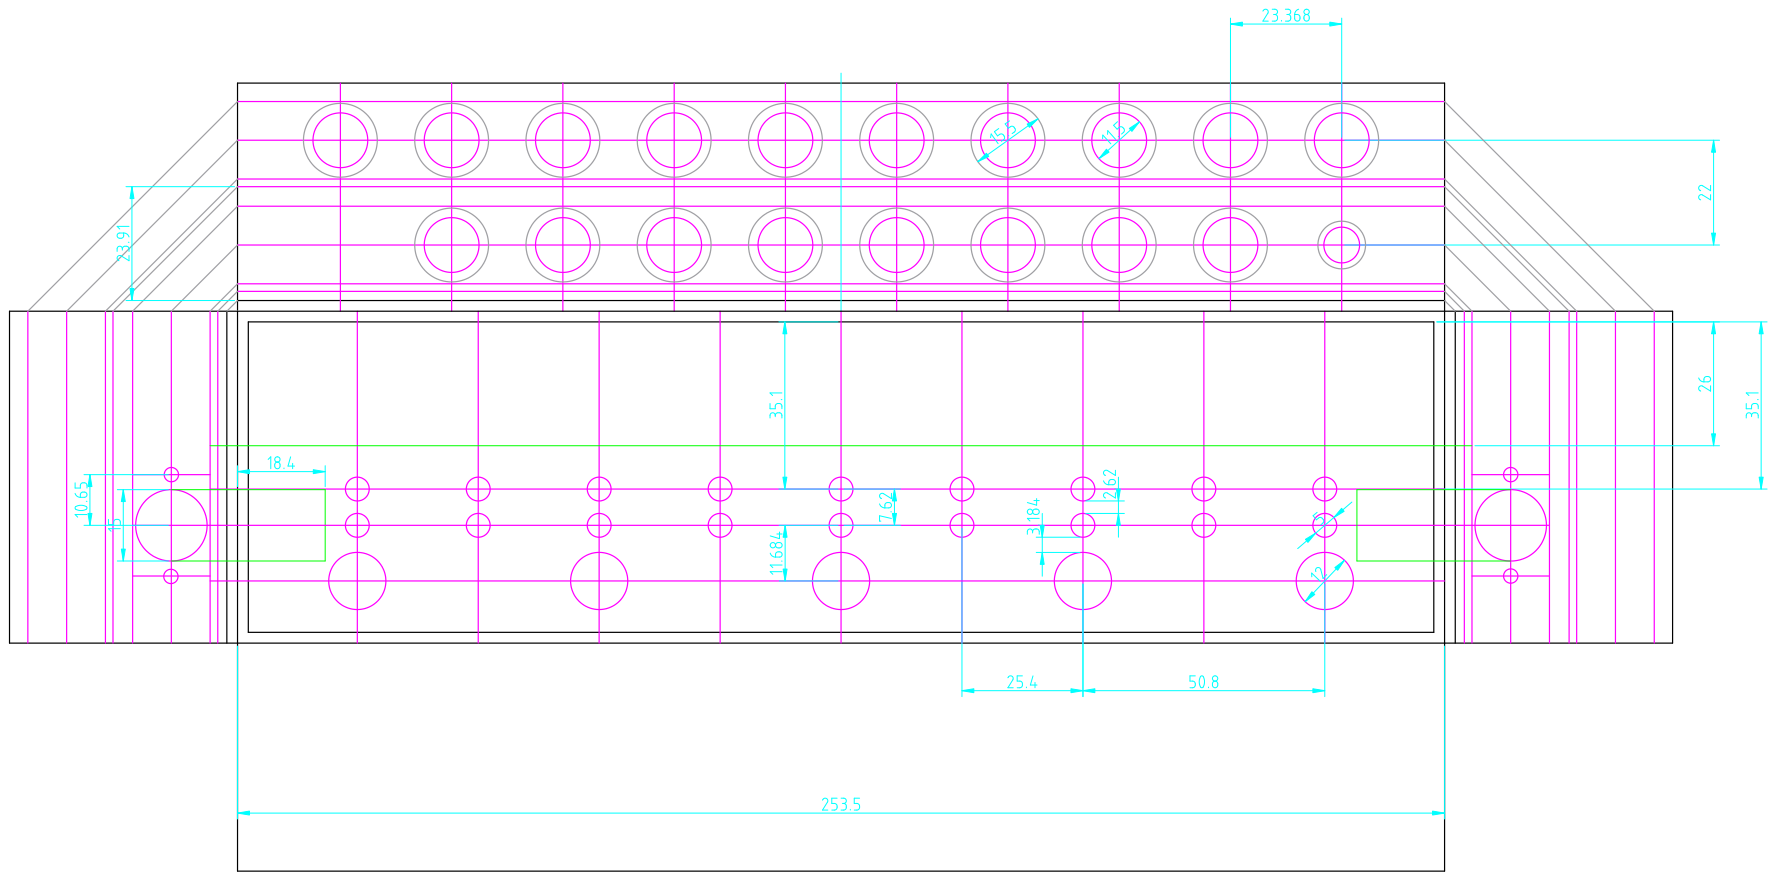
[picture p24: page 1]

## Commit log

2020-11-22 pcb.20200806 documents
    [loop8-bom.csv, loop8-drilling-template.dxf]
2020-11-26 PCB 20201125
    [drilling_template.dxf]
2020-12-08 BOM and schematic for PCB.20201125
    [loop8-bom.csv]
2020-12-29 Fix errata in BOM
    [loop8-bom.csv]
2021-03-20 New PCB designs
    [loop6.csv, loop8.csv]
2021-10-14 pcb.20211003 add schematic
